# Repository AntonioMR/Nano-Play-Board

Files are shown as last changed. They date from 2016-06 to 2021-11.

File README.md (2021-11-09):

# Nano-Play-Board
Esta placa pretende ser una herramienta de iniciación a la experimentación y aprendizaje de recursos de programación y electrónica con la placa [Arduino Nano 3.x][3] o compatibles.
Dispone de varios sensores, actuadores y puertos para la conexión con otras placas de forma que sea posible explotar parte de las funcionalidades de la plataforma Arduino.

[José Juan Sánchez][1] ha desarrollado una librería para usar la placa que que se encuentra disponile en su [cuenta de github][2]. Esta librería permite un uso fácil de los recursos disponibles en la placa mediante el uso de las clases definidas para los distionts elementos y los metodos para la interactuación con los mismos. 

## Sensores
- Una fotoresistencia conectada al pin de entrada analógica A6.
- Un potenciómetro conectado al pin de entrada analógica A7.
- Cuatro pulsadores conectados a los pines PB0-3 del expansor de GPIO.
- Un acelerómetro de tres ejes conectado a los pines A4 y A5 por medio del bus I2C.
- Un encoder incremental de 16 pasos/revolución conectado a los pines D2 y D5.

## Actuadores
- Un buzzer conectado al canal 7 del driver para LED's.
- Un led RGB conectado a los canales 4, 5 y 6 (rojo, azul y verde respectivamente).
- Una matriz de led's conectada a los pines PA0-7 y PB4-7 del expansor de GPIO, para indicar la columna a encender como el patrón a visualizar en la columna. 

## Puertos
- Un zócalo hembra para conectar un detector de objetos por ultrasonidos conectado a los pines D7 y D8.
- Dos zócalos para conectar foto-receptores de infrarrojos tipo CNY-70 conectados a los pines D6 y D9.
- Un zócalo hembra para conectar un sensor de temperatura y humedad tipo DTH11/DTH22 conectado al pin D12.
- Cuatro zócalos macho para conectar servomotores controlados mediante los canales 0-4 del driver para LED's conectado por I2C.
- Un zócalo hembra para conectar un modulo Bluetooth HC-05/HC-6 mediante los pines D10 y D11.
- Un zócalo hembra para conectar un modulo Wifi ESP8266 mediante los pines D10 y D11.
- Cuatro pads para la conexion de sensores capacitivos a los pines A0, A1, A2 y A3.

## Estructura del repositorio
- Raiz: Fuentes del proyecto de la placa de circuito impreso para el software de diseño de PCB [KiCad][4].
- Gerber : Ficheros de fabricacion en formato Gerber de la placa de circuito impreso.
- Imagenes : Renders de la placa de circuito impreso.
- Pdf : Ficheros para el montaje en formato pdf. Esquema del circuito, situacion de componentes, etc.
- Modelos3D : Modelos 3D en formato .wrl para la visualizacion en el proyecto del diseño de la PCB.
- Soft/lib : Librerías para el uso de los distintos elementos presentes en la placa.
- Soft/src : Ejemplos de uso de la placa. 

## Imagenes
Cara superior
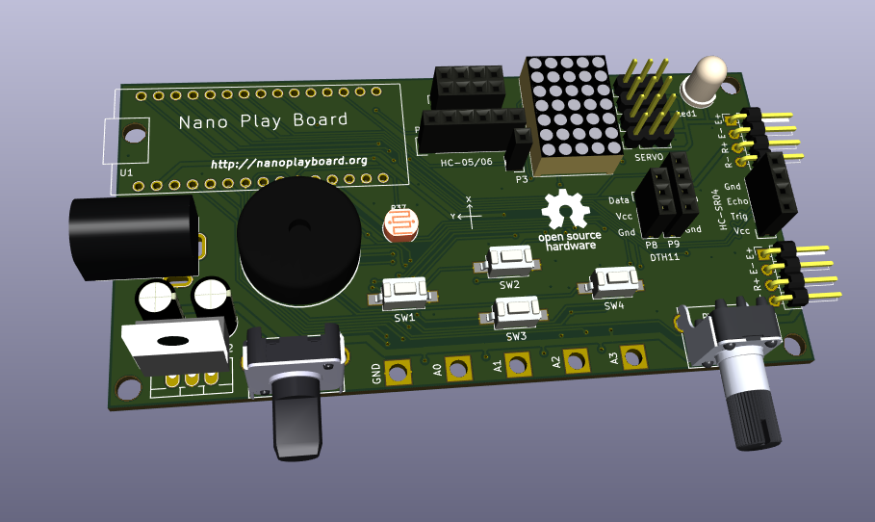
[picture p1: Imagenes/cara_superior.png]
Cara superior


Cara inferior
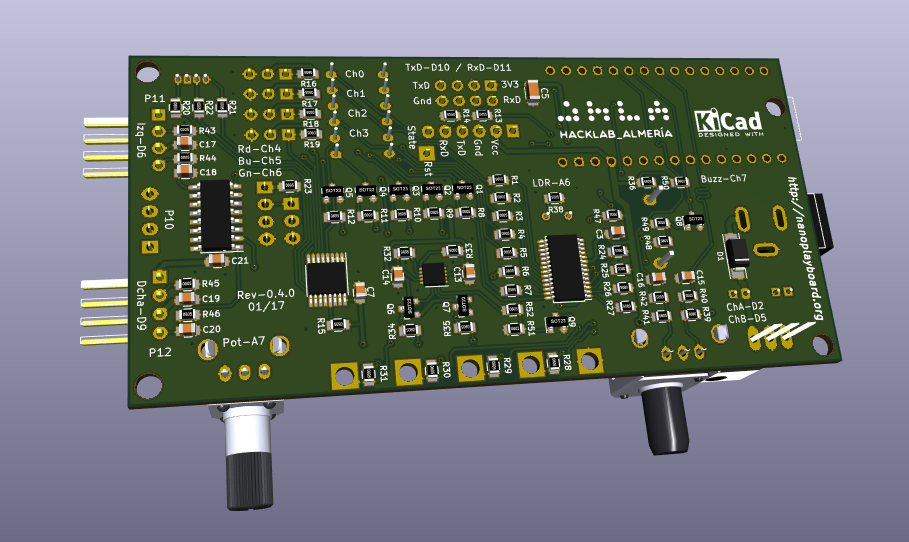
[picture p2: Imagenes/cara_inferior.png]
Cara inferior


## Lista de materiales
Refencias | Valor | Total Uds
----------|-------|-----------
| R1, R2, R20, R21, R22, R3, R4, R5, R6, R7 | [Resistencia 120 Ohm 1/8W](http://www.tme.eu/es/details/crcw0805120rfktabc/resistencias-smd-0805/vishay/) | 10
| R8, R9, R10, R11, R12, R13, R38, R40, R42, R49, R52,  | [Resistencia 1 KOhm 1/8W](http://www.tme.eu/es/details/crcw08051k00fkea/resistencias-smd-0805/vishay/) | 11
| R14 | [Resistencia 2 KOhm 1/8W](http://www.tme.eu/es/details/crcw08052k00fktabc/resistencias-smd-0805/vishay/) | 1
| R23, R32, R33, R34, R35  | [Resistencia 4.7 KOhm 1/8W](http://www.tme.eu/es/details/crcw08054k70fkea/resistencias-smd-0805/vishay/) | 5
| R15, R16, R17, R18, R19, R24, R25, R26, R27, R36, R39, R41, R47, R50 | [Resistencia 10 KOhm 1/8W](http://www.tme.eu/es/details/crcw080510k0fkea/resistencias-smd-0805/vishay/) | 14
| R43, R45  | [Resistencia 220 Ohm 1/8W](http://www.tme.eu/es/details/rc0805fr-07220r/resistencias-smd-0805/yageo/rc0805fr-07220rl/) | 2
| R44, R46, R48, R51  | [Resistencia 47 KOhm 1/8W](http://www.tme.eu/es/details/rc0805fr-0747k/resistencias-smd-0805/yageo/rc0805fr-0747kl/) | 4
| R28, R29, R30, R31 | [Resistencia 10 MOhm 1/8W](http://www.tme.eu/es/details/crcw080510k0fkea/resistencias-smd-0805/vishay/) | 4
| R37 | [Resistencia LDR](http://www.tme.eu/es/details/gm7516/fotoresistencias/wodeyijia/) | 1
| RV1 | [Potenciometro 10K](https://es.rs-online.com/web/p/potenciometros/7293622/)| 1
| C1, C2 | [Condensador electrolitico 0,33 uF 50V](http://www.tme.eu/es/details/uvz1h330mdd/condensadores-electroliticos-tht-105c/nichicon/) | 2
| C18, C20 | [Condensador cerámico 10 nF 25V](http://www.tme.eu/es/details/cl21b103kcannnc/condensadores-mlcc-smd-0805/samsung/) | 2
| C3, C7, C13, C14, C15, C16, C17, C19, C21 | [Condensador cerámico 100 nF 50V](http://www.tme.eu/es/details/cl21b104kbcnnnc/condensadores-mlcc-smd-0805/samsung/) | 7
| C5 | [Condensador ceramico 47 uF 16V](http://www.tme.eu/es/details/cl31a476mqhnnne/condensadores-mlcc-smd-1206/samsung/) | 1
| D1 | [Diodo 15MQ040N](http://www.tme.eu/es/details/15mq040n/diodos-schottky-smd/vishay/15mq040ntrpbf/) | 1
| CON1 | [Conector Barrel Jack 5.5/2.1](http://www.tme.eu/es/details/fc68148/conectores-dc/cliff/) | 1
| P1 | [Tira de pines hembra recto 2x4]() | 1 
| P2 | [Tira de pines hembra recto 1x6]() | 1 
| P4, P5, P6, P7 | [Tira de pines macho recto 1x3]() | 4
| P8 | [Tira de pines hembra recto 1x3]() | 1 
| P10, P9 | [Tira de pines hembra recto 1x4]() | 2 
| P11, P12 | [Tira de pines macho acodado 1x4]() | 2
| P5 | [Tira de pines hembra recto](http://www.tme.eu/es/details/zl262-40sg/regletas-y-enchufes-de-taco/ninigi/) | 3 pines
| P6 | [Tira de pines hembra recto](http://www.tme.eu/es/details/zl262-40sg/regletas-y-enchufes-de-taco/ninigi/) | 4 pines
| U1 | [Arduino Nano](https://www.arduino.cc/en/Main/ArduinoBoardNano) | 1
| U2 | [Regulador de tension 5VDC](http://www.tme.eu/es/details/lm7805ct/estabilizadores-de-tension-no-regulados/fairchild-semiconductor/) | 1
| U3 | [Expansor GPIO, MCP23017](http://www.tme.eu/es/details/mcp23017-e_so/multiplexores-y-conmutadores-analogicos/microchip-technology/) | 1
| U5 | [Matriz de Led's 7x5 Anodo](http://www.tme.eu/es/details/lmd07057bue-101a/pantallas-led-matrices/wenrun/) | 1
| U6 | [Driver para LED 8 canales, PCA9551](http://es.rs-online.com/web/p/drivers-de-display-led/0510730/) | 1
| U8 | [Acelerometro 3 ejes](https://es.rs-online.com/web/p/circuitos-integrados-de-acelerometro/8016873/?sra=pstk) | 1
| U9 | [Inversor CMOS Schmitt Trigger CD40106BM](http://www.tme.eu/es/details/cd40106bm/barreras-inversores/texas-instruments/) | 1
| Q1, Q2, Q3, Q4, Q5, Q8, Q9 | [Transistor NPN SMBT3904](http://www.tme.eu/es/details/smbt3904e6327/transistores-npn-smd/infineon-technologies/)| 7
| Q6, Q7 | [Transistor Mosfet canal N BSS138P](http://www.tme.eu/es/details/bss138p.215/transistores-con-canal-n-smd/nxp/)| 2
| LED1 | [Led RGB 5mm](http://www.tme.eu/es/details/ostama5b31a/diodos-led-tht-5mm/optosupply/)| 1
| SP1 | [Transductor de sonido piezoeléctrico](http://www.tme.eu/es/details/ld-bzpn-1705/transductores-piezoelect-sin-generador/loudity/)| 1
| SW1, SW2, SW3, SW4 | [Pulsador normalmente abierto](http://www.tme.eu/es/details/dtsm31nb/micro-conmutadores-tact-pcb/canal-electronic/dtsm-31n-b/)| 4
| B1 | [Codificador giratorio 2 canales](http://es.rs-online.com/web/p/codificadores-giratorios-mecanicos/6234215/)| 1

## Pines
Referencia | Pin 
----------|-------
| USB Tx | D0 |
| USB Rx | D1 |
| Encoder canal A | D2 |
| Interrupción Acelerómetro / Expansor GPIO | D3 |
| Reset perifericos | D4 |
| Encoder canal B | D5 |
| Infrarrojos Izquierdo | D6 |
| Ultrasonidos Echo | D7 |
| Ultrasonidos Trigg | D8 |
| Infrarrojos Derecho | D9 |
| Inalámbrico Tx | D10 |
| Inalámbrico Rx |  D11 |
| Sensor DTH Dato | D12 |
| Libre (LED Arduino) | D13 |
| Pad para sensor capacitivo 0 | A0 |
| Pad para sensor capacitivo 1 | A1 |
| Pad para sensor capacitivo 2 | A2 |
| Pad para sensor capacitivo 3 | A3 |
| I2C - SDA | A4 |
| I2C - SCL | A5 |
| LDR | A6 |
| Potenciometro | A7 |

## Licencia
Este diseño es Software Libre; usted puede redistribuirlo y/o modificarlo bajo los términos de la "GNU General Public License" como lo publica la "FSF Free Software Foundation", o (a su elección) de cualquier versión posterior.

Este diseño es distribuido con la esperanza de que le sea útil, pero SIN NINGUNA GARANTIA; incluso sin la garantía implícita por la VENTA o EJERCICIO DE ALGUN PROPOSITO en particular. Vea la "GNU General Public License" para más detalles.

## Creditos
Los modelos 3D de los siguientes componentes están creados a partir de los modelos originales indicados a continuación:

Componente | Autor | Modelo 
-----------|-------|--------
| Arduino Nano V3 | [Carlos AG][5] | [Modelo][6] 
| Bluetooth HC-06 | [Felix Georgievich ILgach][7] | [Modelo][8] 
| Detector HC-SR04 | [Renato Alonso Hurtado Medina][9] | [Modelo][10] 

[1]: http://josejuansanchez.org
[2]: https://github.com/josejuansanchez/NanoPlayBoard/
[3]: https://www.arduino.cc/en/Main/ArduinoBoardNano
[4]: http://kicad.org/
[5]: http://www.3dcontentcentral.com/Contributors.aspx?id=669699
[6]: http://www.3dcontentcentral.com/parts/download-part.aspx?id=387975&catalogid=171
[7]: http://www.3dcontentcentral.com/Contributors.aspx?id=1658685
[8]: http://www.3dcontentcentral.com/download-model.aspx?catalogid=171&id=542660
[9]: http://www.3dcontentcentral.com/Contributors.aspx?id=1704559
[10]: http://www.3dcontentcentral.com/download-model.aspx?catalogid=171&id=655885

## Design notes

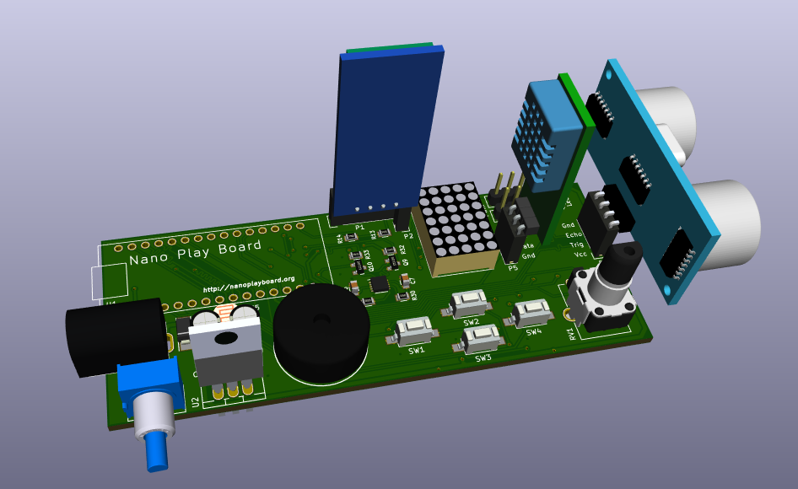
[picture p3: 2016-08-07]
Imagenes/Sensores_cara_superior.png

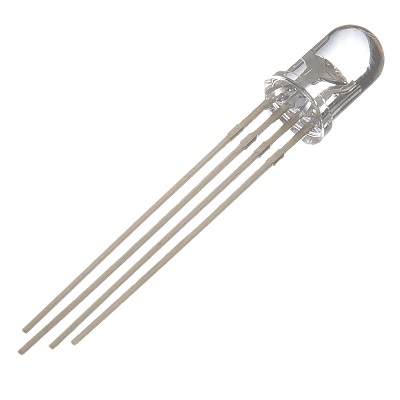
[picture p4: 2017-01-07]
Imagenes/rgb-led.jpg

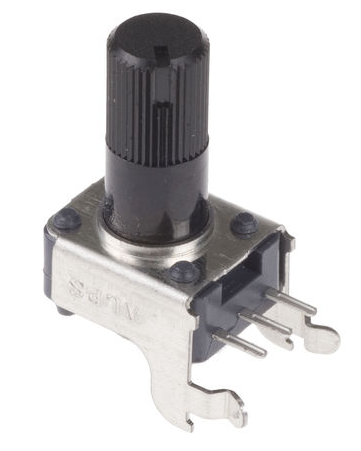
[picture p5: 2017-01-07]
Imagenes/Potenciometro.png

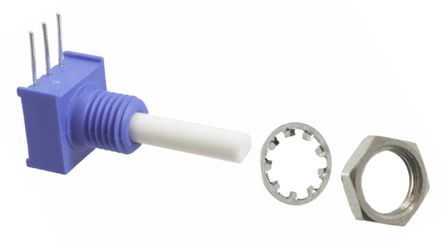
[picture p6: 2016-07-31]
Imagenes/Encoder_3315C.jpg

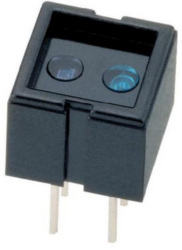
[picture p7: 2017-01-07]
Imagenes/CNY70.jpg

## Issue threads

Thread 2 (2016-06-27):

Pin A7 usado como salida

AntonioMR, 2016-06-27:
Los pines A6 y A7 son pines analógicos puros y no pueden usarse como E/S digitales.
La placa utiliza el pin A7 para la carga de las salidas en el registro de desplazamiento y es necesario puentearlo con el pin D6, que está libre para poder usarse el registro.

AntonioMR, 2016-07-18:
Corregido en la revisión "a" de la placa. Para las versiones anteriores es necesario realizar un puente externo

Closed 2016-07-18.

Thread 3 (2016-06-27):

Propuesta - Utilizar 2 salidas PWM para controlar 2 servos

josejuansanchez, 2016-06-27:
Para una nueva versión estaría genial usar 2 salidas PWM para controlar dos servos.
Se podrían poner dos tiras de 3 pines macho, para controlar la señal PWM, el voltaje y la tierra.
Aquí pongo una imagen de una placa que usa estas tiras de pines.

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

AntonioMR, 2016-08-07:
Se han añadido dos conectores macho de tres pines en la versión 0.2 de la placa controlados por los pines D5 y D6 junto con VCC y GND

Closed 2016-08-07.

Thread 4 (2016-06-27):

Propuesta - Añadir un pulsador

josejuansanchez, 2016-06-27:
También se podría incluir un pulsador para permitir realizar experimentos que incluyan este nuevo elemento. De este modo incrementamos el número de prácticas que se pueden realizar con la placa.

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

AntonioMR, 2016-07-21:
Seria interesante añadir incluso varios aunque hubiera que añadir un codificador de 8 a 3 lineas y leer mediante 3 bits hasta 8 pulsadores.
En cualquier caso, uno es imprescindible.

AntonioMR, 2016-08-07:
Añadidos 4 pulsadores conectados mediante un codificador de prioridad en la versión 0.2

Closed 2016-08-07.

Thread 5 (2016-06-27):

Propuesta - Añadir una tira de 4 pines hembra para un sensor de ultrasonidos

josejuansanchez, 2016-06-27:
Estaría bien incluir una tira de 4 pines hembra para poder conectar un sensor de ultrasonidos directamente en la placa.

En la imagen se muestra el tipo de sensor de ultrasonido con los que la placa podría ser compatible.

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

josejuansanchez, 2016-07-21:
No tengas en cuenta esta propuesta, creo que es mejor utilizar pines macho como los que usan en esta placa:

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

AntonioMR, 2016-07-21:
No me parece mala idea poner un zócalo hembra para insertar directamente el modulo, seria mas practico que tener que andar poniendo cables.
La sigo teniendo en mente.

AntonioMR, 2016-08-07:
Añadido en la versión 0.2

Closed 2016-08-07.

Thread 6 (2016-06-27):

Propuesta - Añadir una tira de 4 pines hembra para conectar un módulo bluetooth

josejuansanchez, 2016-06-27:
Se podrían incluir 4 pines hembra para conectar directamente un módulo de bluetooth sobre la placa.

La placa podría ser compatible con los módulos bluetooth HC-05 y HC-06.

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

josejuansanchez, 2016-07-21:
Creo que esto no sería necesario, he estado haciendo pruebas con un módulo bluetooth HC-05 conectado a los pines  **D7 (Rx)** y **D8 (Tx)** y creo que así está perfecto.

Lo que sí podría ser interesante es añadir dos pines macho adicionales de **+5v** y **GND** junto a los pines **Rx** y **Tx**.

AntonioMR, 2016-07-21:
La idea original de esos pines era conectarse con otras placas iguales para comunicarse. Sin duda con los pines de alimentación mucho mas practico para conectar directamente el modulo blueooth.

Closed 2016-07-21.

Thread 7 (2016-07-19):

Propuesta - Añadir un pequeño sensor de temperatura similar al de `LightBlue Bean`

josejuansanchez, 2016-07-19:
Se podría estudiar la posibilidad de incluir un pequeño sensor de temperatura similar al que lleva la placa `LightBlue Bean`.

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

AntonioMR, 2016-08-07:
Se añade un zócalo para un sensor DTH11/DTH22 en la versión 0.2 de la placa

Closed 2016-08-07.

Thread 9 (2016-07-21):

Propuesta - Pinout para la próxima versión

josejuansanchez, 2016-07-21:
Aquí dejo una posible propuesta de cómo podría ser el *pinout* de la próxima versión.
He resaltado en negrita los cambios que he propuesto respecto a la versión actual.

## Pines
Referencia | Pin
----------|-------
| **Rx**. Para el módulo Bluetooth | **D0** |
| **Tx**. Para el módulo Bluetooth | **D1** |
| Activación de la primera columna de la matriz | D2 |
| Altavoz piezoelectrónico | D3 (PWM) |
| Activación de la segunda columna de la matriz | D4 |
| **Servo**. (Pines macho) | **D5 (PWM)** |
| **Servo**. (Pines macho) | **D6 (PWM)** |
| **Sensor IR**. (Pines macho) | **D7** |
| **Sensor IR**. (Pines macho) | **D8** |
| Pin Rojo RGB | D9 (PWM) |
| Pin Verde RGB | D10 (PWM) |
| Pin Azul RGB | D11 (PWM) |
| Dato de entrada al registro de desplazamiento | D12 |
| Reloj de carga serie del registro de desplazamiento | D13 |
| Fotoresistencia | A0 |
| Potenciometro | A1 |
| Activación de la cuarta columna de la matriz | A2 |
| Activación de la quinta columna de la matriz | A3 |
| **Activación de la tercera columna de la matriz** | **A4** |
| **Reloj de carga de las salidas del registro de desplazamiento** | **A5** |
| **Pulsador** | **A6** |
| **¿Pulsador o Sensor de temperatura?** | **A7** |

AntonioMR, 2016-07-21:
Muchas gracias por todas las sugerencias, sin duda mejoraran mucho la placa y la haran mas util a la hora de enseñar cosas con ella. Te comento lo que tenia en mente para la evolucion de la placa.
Tenia en mente añadir un segundo registro en serie con el primero para controlar la activación de las columnas de la matriz, de modo que el primer byte enviado es el dato de la columna y el segundo la columna o columnas que se activara. Esto libera 5 pines digitales. de los que tres quería utilizar para el codificador de los pulsadores
Los pines A4 y A5 como son los que implementan el bus I2C tenia pensado aprovecharlos para conectar algún tipo de acelerómetro, sensor Tª o cualquier sensor I2C que se integrara dentro de la placa.
Como el pin D2 soporta una interrupción externa ando dándole vueltas a como utilizarlo para que se pueda aprovechar esta funcionalidad, había pensado en un contador de pulsos o algo así.
Para añadir todo esto en el mismo espacio, todas las resistencias y probablemente los transistores pasen a versiones SMD de un tamaño razonable como para que se puedan soldar con relativa facilidad.

josejuansanchez, 2016-07-21:
La evolución de la placa que propones me parece brillante!

AntonioMR, 2016-08-07:
Finalmente la versión 0.2 de la placa ha quedado con la siguiente distribución de pines

## Pines
Referencia | Pin
----------|-------
| Tx. Para el módulo Bluetooth | D0 |
| Rx. Para el módulo Bluetooth | D1 |
| Encoder canal A | D2 |
| Altavoz piezoelectrico | D3 (PWM) |
| Reloj de carga de las salidas de los registros | D4 |
| Servo 1. (Pines macho) | D5 (PWM) |
| Servo 2. (Pines macho) | D6 (PWM) |
| Ultrasonidos Echo. (Pines macho) | D7 |
| Ultrasonidos Trig. (Pines macho) | D8 |
| Pin Rojo RGB | D9 (PWM) |
| Pin Verde RGB | D10 (PWM) |
| Pin Azul RGB | D11 (PWM) |
| Dato de entrada al registro de desplazamiento | D12 |
| Reloj de carga serie del registro de desplazamiento | D13 |
| Pulsadores bit 0 | A0 |
| Pulsadores bit 1 | A1 |
| Encoder canal B | A2 |
| Dato sensor Tª/HR  | A3 |
| Linea SDA del bus I2C para conexión con acelerómetro | A4 |
| Linea SCL del bus I2C para conexión con acelerómetro| A5 |
| Fotorresistencia | A6 |
| Potenciómetro | A7 |

josejuansanchez, 2016-09-16:
Creo que no ha sido buena idea usar los pines `D0` y `D1` para el módulo Bluetooth. Tenías razón, nos limita las posibilidades de uso de la placa y no es nada cómodo estar quitando el módulo Bluetooth cada vez que se sube un *sketch*.

Siento haberte dado la lata para que lo cambiaras :(
Si se puede cambiar en la próxima versión estaría genial.

AntonioMR, 2016-09-16:
En la próxima versión, si todos los pines PWM pasan a controlarse mediante un driver para leds controlado por I2C, se liberarían 6 pines:
2 para puerto serie destinado a comunicaciones inalámbricas (bluetooth, wifi, xbee ...)
1 para la interrupción del acelerómetro
2 para el decodificador de pulsadores y poder controlar hasta 8 pulsadores (un piano? seria genial poder llegar hasta doce y poder tener una octava con los semitonos y todo). Sobre todo pensando en la placa como controladora midi lanzando samplers.
quedaría uno libre que ya se nos ira ocurriendo, quizás para aumentar el numero de pulsadores.

AntonioMR, 2016-09-25:
Una propuesta para la proxima revision:

## Pines
Referencia | Pin
----------|-------
| Tx. Para la comunicación USB | D0 |
| Rx. Para la comunicación USB | D1 |
| Encoder canal A | D2 |
| Canal de interrupcion del acelerometro | D3 (PWM) |
| Reloj de carga de las salidas de los registros | D4 |
| Tx. Para el módulo Bluetooth | D5 (PWM) |
| Rx. Para el módulo Bluetooth | D6 (PWM) |
| Ultrasonidos Echo. (Pines macho) | D7 |
| Ultrasonidos Trig. (Pines macho) | D8 |
| Pulsadores bit 2 | D9 (PWM) |
| Pulsadores bit 3 | D10 (PWM) |
| Pulsadores bit pulsación | D11 (PWM) |
| Dato de entrada al registro de desplazamiento | D12 |
| Reloj de carga serie del registro de desplazamiento | D13 |
| Pulsadores bit 0 | A0 |
| Pulsadores bit 1 | A1 |
| Encoder canal B | A2 |
| Dato sensor Tª/HR  | A3 |
| Linea SDA del bus I2C para conexión con acelerómetro y driver de LED's | A4 |
| Linea SCL del bus I2C para conexión con acelerómetro y driver de LED's | A5 |
| Fotorresistencia | A6 |
| Potenciómetro | A7 |

Se utilizaría un codificador con prioridad de 16 a 4 para leer el estado de 12 pulsadores distribuidos como teclado de piano formando una octava.

Los 2 servos, el buzzer y el led RGB pasarían a estar controlados por el driver para LED PCA9685 capaz de generar hasta 16 señales PWM independientes. Se utilizarían 5 y el resto se pueden utilizar para encender LED's junto a los pulsadores

MiguelAngelLV, 2016-11-21:
Para una futura revisión, se podría cambiar el LED RGB por uno basado en el ws2812, estos requieren un solo pin PWM. Quizás sea más fácil que usar el bus del i2c o dejarlo libre para otro dispositivo.

También, para ahorrar 1 GPIO en los botoenes, podríamos usar este esquema:

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

Con 3 PINs podríamos tener hasta 6 botones. Envías corriente por A0, si recibes en A1 estás pulsando el B0 y si te llega por el A2 estás pulsando el B1.

Ahora cambias el modo y envías por A1, si recibes por A0 estás pulsando B2 y si recibes por A2 estás pulsando B3.

Igualmente podríamos hacerlo enviando por A2 y comprobando A0 y A1 para obtener 2 botones más.

Tendríamos que tener unos delays de microsegundos (pongamos 20 microsegundos por par de botones), pero no creo que sea apreciable.

AntonioMR, 2016-11-21:
Interesantes ambas propuestas, tomo nota.

MiguelAngelLV, 2016-11-21:
Chachi. Bueno, se me había olvidado comentar que los LEDs ws2812 puedes ponerlos en serie y conectar todos los que quieras. Así con un solo PIN puedes poner todos los LEDs que te de la gana. Yo creo que con 4 podrían hacerse cosas muy chulas.

AntonioMR, 2017-01-04:
Propuesta para la V3 de la placa

| Referencia | Pin |
| --- | --- |
| Tx. Para la comunicación USB | D0 |
| Rx. Para la comunicación USB | D1 |
| Encoder canal A | D2 |
| Canal de interrupcion del acelerometro | D3 (PWM) |
| Reloj de carga de las salidas de los registros | D4 |
| Encoder canal B | D5 (PWM) |
| Infrarrojos Izquierdo | D6 (PWM) |
| Ultrasonidos Echo. (Pines macho) | D7 |
| Ultrasonidos Trig. (Pines macho) | D8 |
| Infrarrojos Derecho | D9 (PWM) |
| Tx. Para el módulo Bluetooth  | D10 (PWM) |
| Rx. Para el módulo Bluetooth  | D11 (PWM) |
| Dato de entrada al registro de desplazamiento | D12 |
| Reloj de carga serie del registro de desplazamiento | D13 |
| Pulsadores bit 0 | A0 |
| Pulsadores bit 1 | A1 |
| Pulsadores - Detección pulsación | A2 |
| Dato sensor Tª/HR | A3 |
| Linea SDA del bus I2C para conexión con acelerómetro y driver de LED's | A4 |
| Linea SCL del bus I2C para conexión con acelerómetro y driver de LED's | A5 |
| Fotorresistencia | A6 |
| Potenciómetro | A7 |

Incluiría un driver para Led controlado por I2C para 8 canales (4 servos, Led RGB)

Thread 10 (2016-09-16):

Errata en la serigrafía de los pines del registro de desplazamiento de la nueva placa Rev-0.2

josejuansanchez, 2016-09-16:
Los pines del registro de desplazamiento aparecen en la placa como:

```
Din    = D13
ClkIn  = D12
ClkOut = D4
```

pero en el esquema aparecen como:

```
Din    = D12
ClkIn  = D13
ClkOut = D4
```

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

AntonioMR, 2016-09-16:
Gracias por avisar.
La serigrafía esta mal, están rutados conforme al esquema!

Closed 2016-09-16.

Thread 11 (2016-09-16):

El pulsador superior esta inutilizado

AntonioMR, 2016-09-16:
De la forma que están conectados los pulsadores al decodificador no es posible utilizar el pulsador superior ya que seria necesario comprobar el estado del pin de salida GS del decodificador.

AntonioMR, 2016-11-21:
Una posible solución para utilizar el pulsador con las placas versiones 0.2.0 y 0.2.1 es tirar un hilo entre el terminal GS del codificador (patilla 14) y el pin 2 en el zócalo para la conexión del sensor DHT11.
De esta forma se utilizará el Pin A3 del Arduino Nano como entrada digital. Está estará a nivel bajo si algun pulsador está activo. La combinacion de los pines A0 y A1 será
A0 | A1 | Pulsador
 0  |   0  | Arriba
 1  |   0  | Izquierda
 0  |   1  | Derecha
 1  |   1  | Abajo

AntonioMR, 2017-01-25:
Corregido a partir de la V0.3

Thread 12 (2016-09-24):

Controlar las señales PWM mediante un driver para LED's

AntonioMR, 2016-09-24:
Añadir un driver para LED'S controlado medante I2C para las señales PWM de los servos, Led RGB y buzzer, y así dejar libres esas salidas del micro para otras funciones.

AntonioMR, 2017-01-25:
Realizado a partir de la V0.3

Closed 2017-01-25.

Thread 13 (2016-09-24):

Conectar la salida de interrupción del acelerómetro

AntonioMR, 2016-09-24:
Conectar la salida de interrupción de acelerómetro al pin D3 del arduino de forma que se pueda hacer uso de la capacidad de generar interrupciones del chip MMA7660FC.
Previamente ha de liberarse este pin que se usa para generar la señal PWM del buzzer

AntonioMR, 2017-01-25:
Conectado a partir de la versión V0.3

Closed 2017-01-25.

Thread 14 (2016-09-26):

Observaciones sobre la NanoPlayBoard Rev-0.2

josejuansanchez, 2016-09-26:
- Me gustaba más el tacto del potenciómetro de la versión anterior de la placa. El de la versión actual resbala un poco y no gira con tanta suavidad como el otro.
- Cuando el sensor de ultrasonidos está montado en la placa resulta un poco complicado manipular el potenciómetro.
- He tenido algunos problemas de conexión con mi sensor DHT 11, no hacía buen contacto, tenía que moverlo o mantenerlo presionado para que hiciese buen contacto. También habría que revisar el orden de los pines hembra de la placa, porque puede ser que no coincida con los pines del sensor. Propongo buscar un sensor de temperatura barato e integrarlo en la placa directamente como el acelerómetro.
- Estaría bien añadir algunos pines macho de propósito general para poder conectar otros sensores/actuadores de otros kits de robótica/electrónica. Por ejemplo serían ideales para conectar dos sensores de infrarrojos y poder hacer un robot siguelíneas. Yo propondría entre 2 y 4 pines más de propósito general siguiendo el mismo estilo de los pines actuales de los servos (Señal, Vcc y Gnd).
- Habría que ver la posibilidad de poner los pines macho de diferentes colores, rojo para Vcc, negro para Gnd y otro color diferente para la Señal. Esto podría ser de ayuda a los más pequeños a la hora de conectar los componentes a la placa.
- ¿Sería posible añadirle algunos pads para usarlos como sensores capacitivos? Adafruit ha sacado hace poco una placa que los tiene, [aquí le puedes echar un vistazo](https://www.adafruit.com/product/3000).
- Para poder añadir un ESP8266 necesitaríamos dos pines de 3.3v. ¿Sería posible añadirlos en la próxima versión?

AntonioMR, 2016-09-26:
Gracias por los comentarios @josejuansanchez

El gran problema de la placa es el espacio. La próxima versión será de 100x50 mm (10 mm mas ancha) ya que tiene el mismo coste y ayudara a distribuir mejor los componentes. Esto ayudará con la usabilidad del potenciómetro cuando el sensor de ultrasonidos este conectado (cosa que ya me temía viendo el modelo en 3D) y del sensor de Tª que también se queda muy justo sobre los conectores de los servos.
Coincido contigo en el sensor de Tª integrado en la placa, y si es I2C liberará un pin para nuevos propósitos.

Lo del potenciómetro tiene fácil solución ya que el otro creo que era incluso mas barato. A mi particularmente me gusta mas el tacto de este, con el punto central claramente identificado en la carrera, pero vamos, ambos utilizan la misma huella por lo que poner uno u otro es cosa simple.

Lo de los pines de propósito general me parece interesante, aunque dado la densidad de señales que tratamos de controlar con la placa probablemente tenga que compartir funcionalidad con alguna otra característica. Intentare ver la forma de tener al menos 2 con dedicación exclusiva.

Lo de los pines de colores es una mera cuestión de coste. Lo tendré en cuenta a la hora de diseñarlo ya que si se posicionan los conectores adecuadamente lo mismo no incrementa mucho el coste y es verdad que es una gran ayuda. Mucho mas intuitivo que las indicaciones en la serigrafía.

Me gusta lo de la posibilidad de tener pads para usar sensores capacitivos y mas aun si estos compartieran pin físico en el arduino con los pulsadores físicos. Me temo que esto implicaría no aumentar el numero de pulsadores y que cada uno utilice un pin físico del Arduino. Le daré un vistazo a la opción de 4 pulsadores con pad en el borde de la placa al que conectar los posibles sensores.

Lo del ESP8266 no tiene mayor problema, solo que lo mas probable es que comparta pines con el modulo bluetooth (dos distintos al D0 y D1 utilizado por el USB)

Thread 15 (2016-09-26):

Comprobar la distribución de pines en el sensor DHT11

AntonioMR, 2016-09-26:
La placa utiliza una distribución de pines VCC, Data, GND. Algunos de estos sensores utilizan VCC, GND, Data.

AntonioMR, 2017-01-25:
La Version V0.4 corrige este problema y además incorpora zócalos para conectar tanto la versión de 3 pines cómo la de 4

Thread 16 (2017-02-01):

Modificacion en Encoder a partir de V0.2.1

AntonioMR, 2017-02-01:
A partir de la versión V0.2.1 se monta un encoder con mas pasos por revolución y es necesario bajar los valores de los condensadores y resistencias del filtro anti-rebotes. Con los valores especificados en el esquema se obtienen resultados erráticos a baja velocidad de giro.
Se ha probado el encoder con valores de 1KOhm para las resistencias y 100nF para los condensadores obteniendo resultados según lo esperado. Las resistencias de pull-up se mantienen a 10KOhm.

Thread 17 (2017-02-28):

Huella de U3 no corresponde

AntonioMR, 2017-02-28:
En la version V0.4.0 se utiliza la huella del paquete TSSOP28 cuando el encapsulado es un SSOP28.
Se corregirá en la siguiente revision

AntonioMR, 2017-03-03:
Corregido en V0.4.1

Closed 2017-03-23.

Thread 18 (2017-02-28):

La huella de U9 no corresponde

AntonioMR, 2017-02-28:
En la version V0.4.0 se ha utilizado una huella para SOIC16 cuando el encapsulado es un SOIC14.
En necesario realizar puentes de forma externa para que pueda funcionar esta PCB.
Pendiente de corregir en la siguientes revision

AntonioMR, 2017-03-03:
corregido en V0.4.1

Closed 2017-03-23.

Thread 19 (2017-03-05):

Driver para led no permite ciclos de trabajo independientes por canal

AntonioMR, 2017-03-05:
El driver para led PCA9551 solo permite dos ciclo de trabajo configurables para todos los canales.
Es necesario utilizar un driver con control independiente para cada canal, como por ejemplo el PCA9684

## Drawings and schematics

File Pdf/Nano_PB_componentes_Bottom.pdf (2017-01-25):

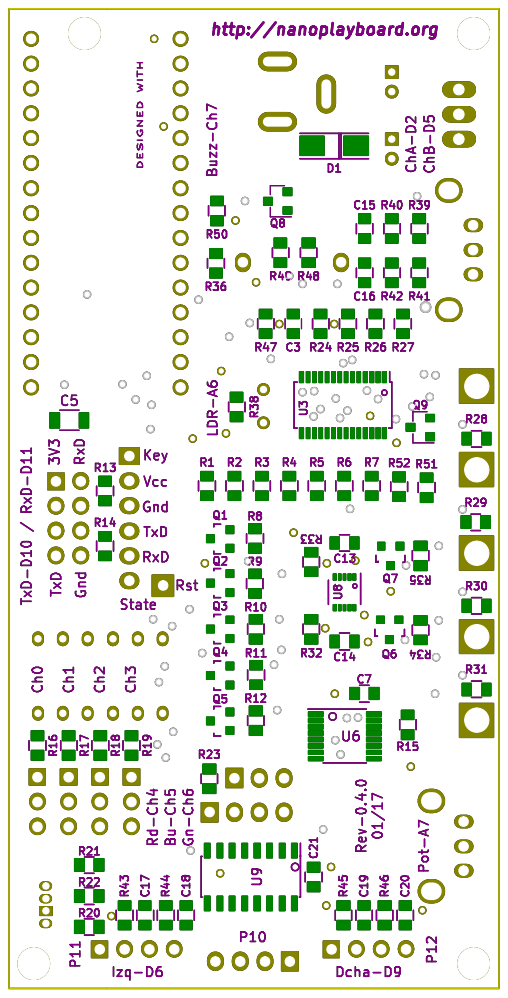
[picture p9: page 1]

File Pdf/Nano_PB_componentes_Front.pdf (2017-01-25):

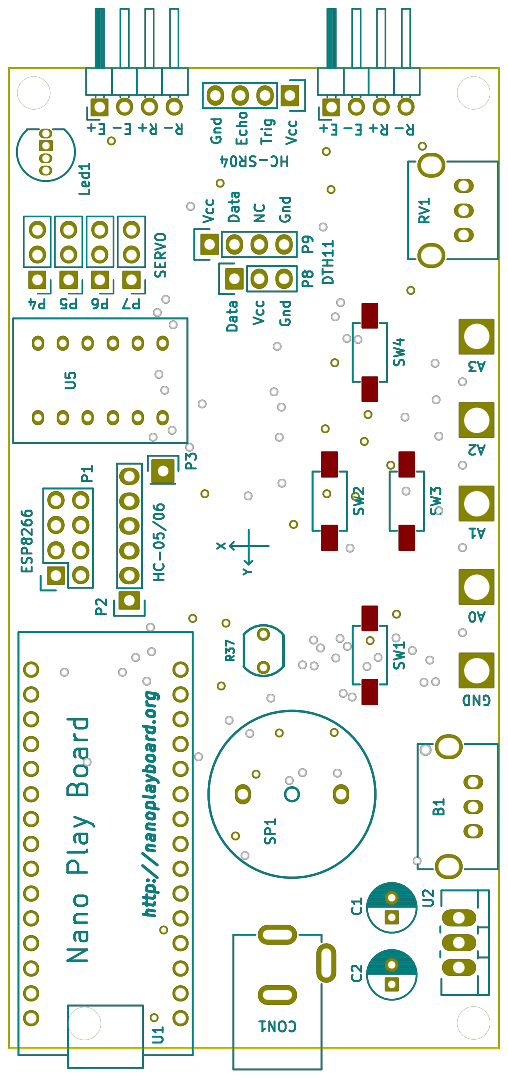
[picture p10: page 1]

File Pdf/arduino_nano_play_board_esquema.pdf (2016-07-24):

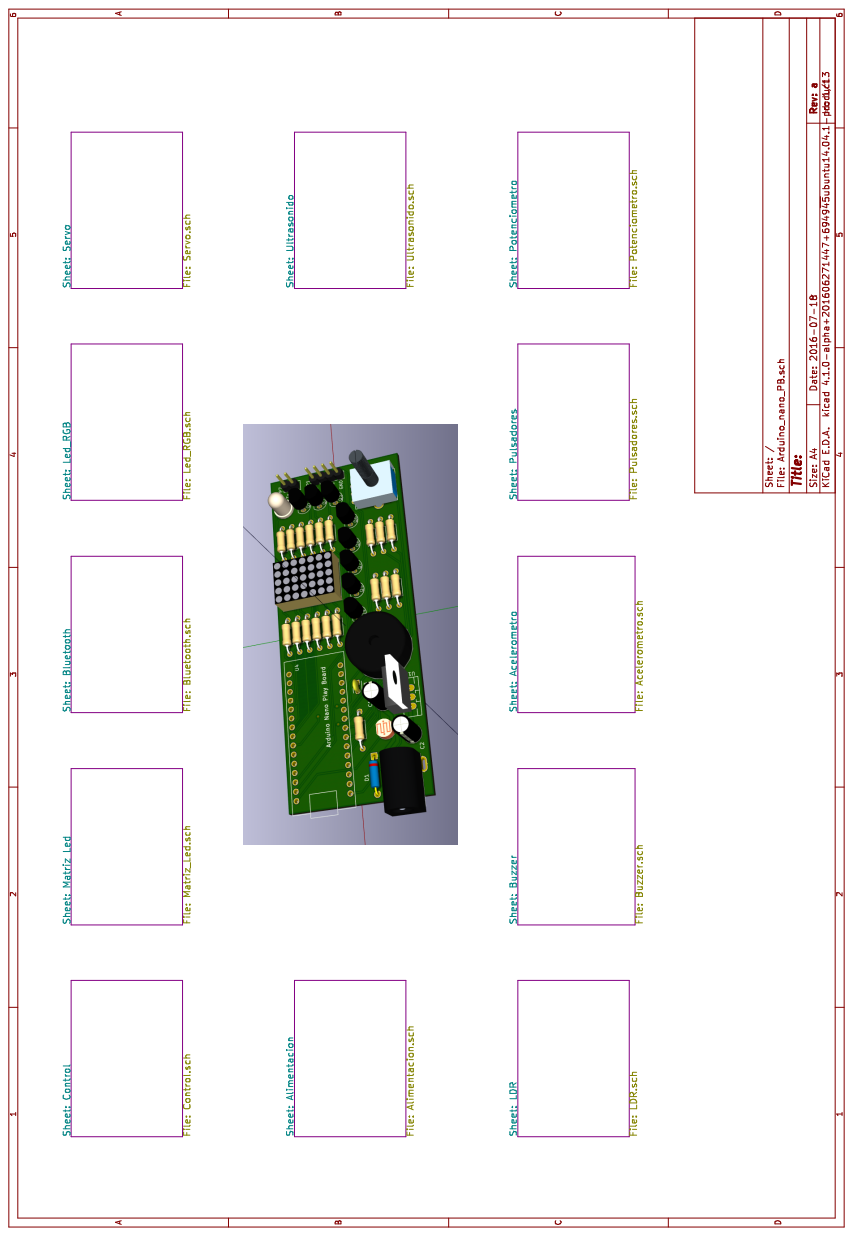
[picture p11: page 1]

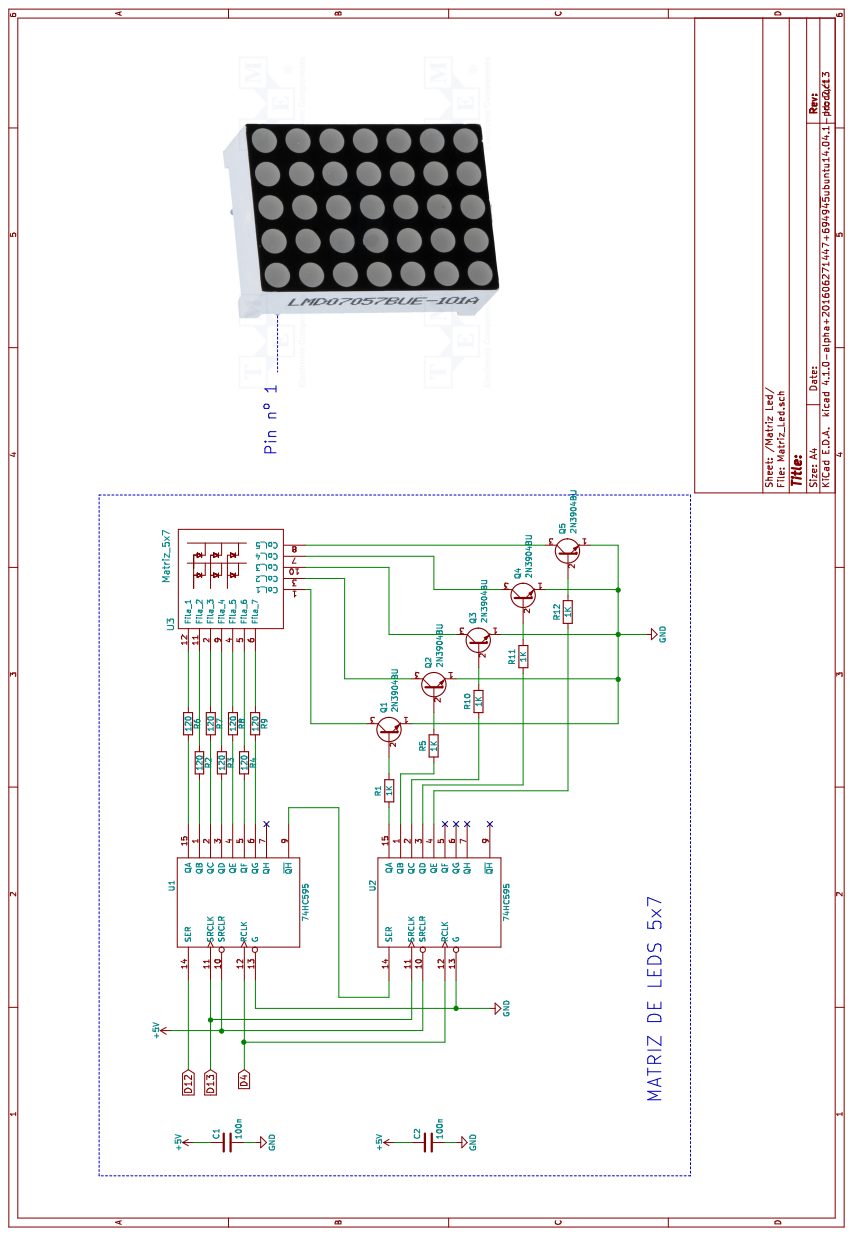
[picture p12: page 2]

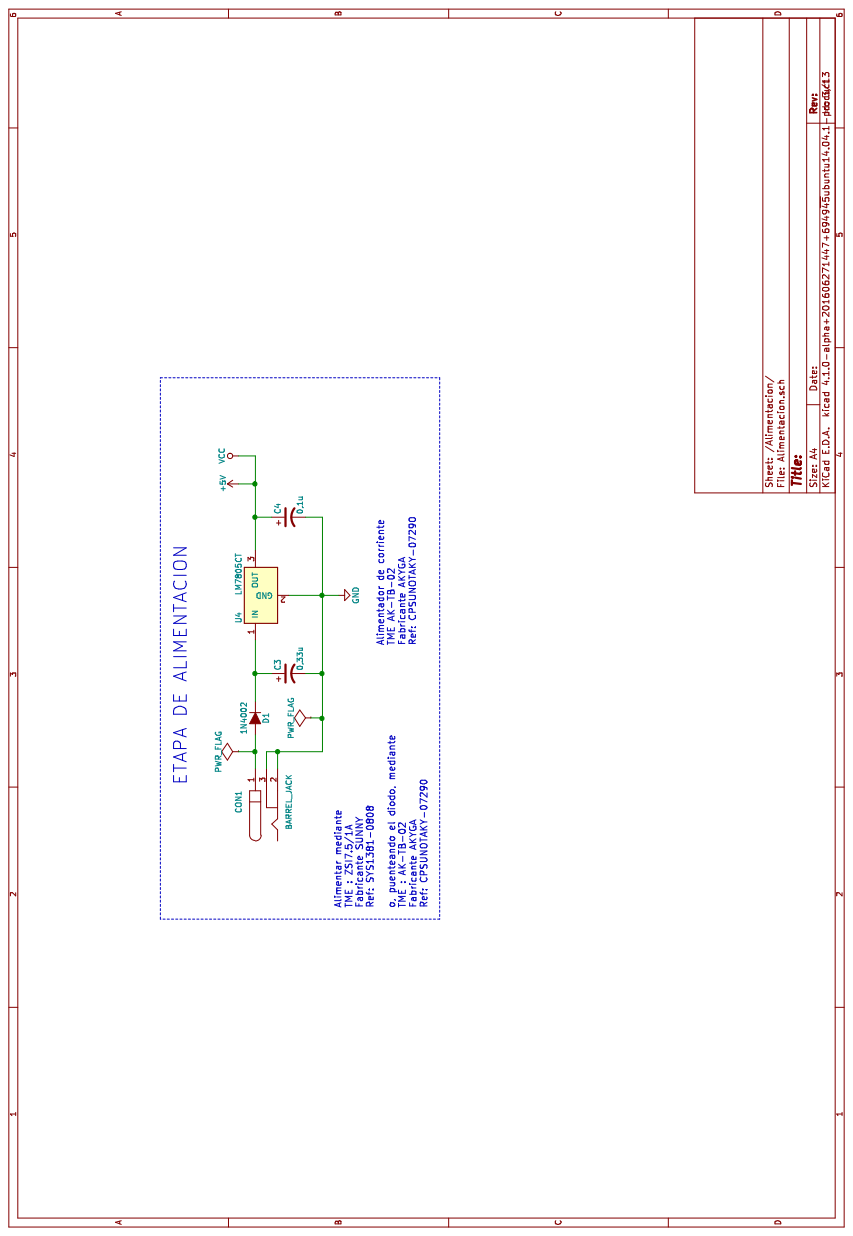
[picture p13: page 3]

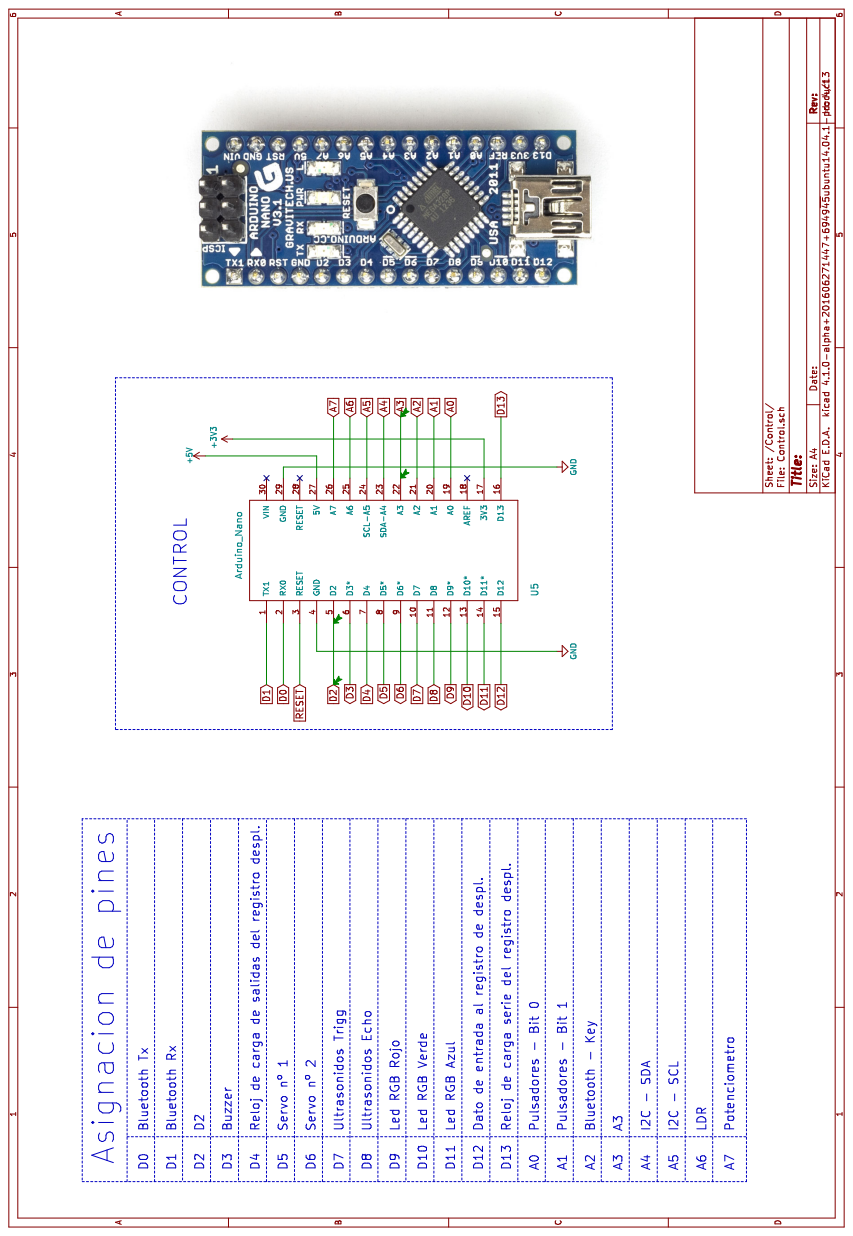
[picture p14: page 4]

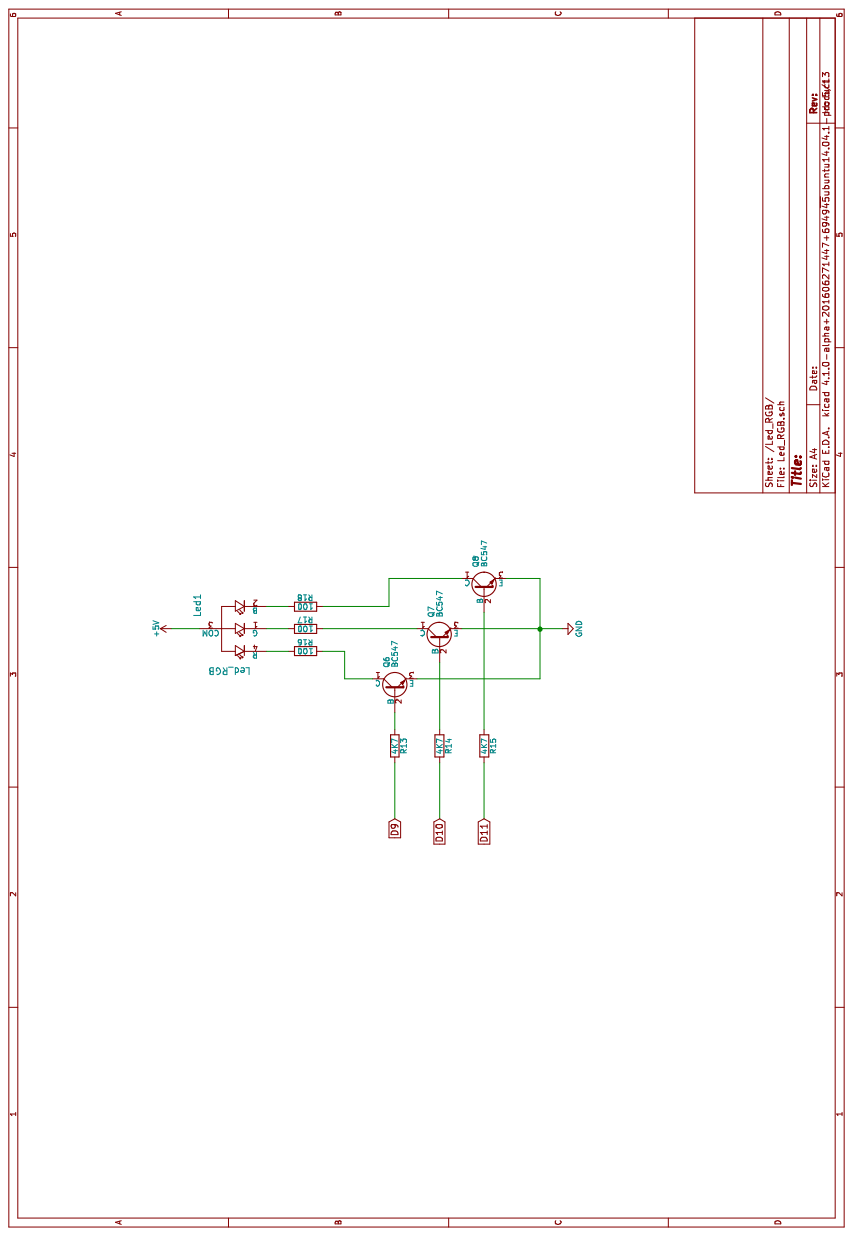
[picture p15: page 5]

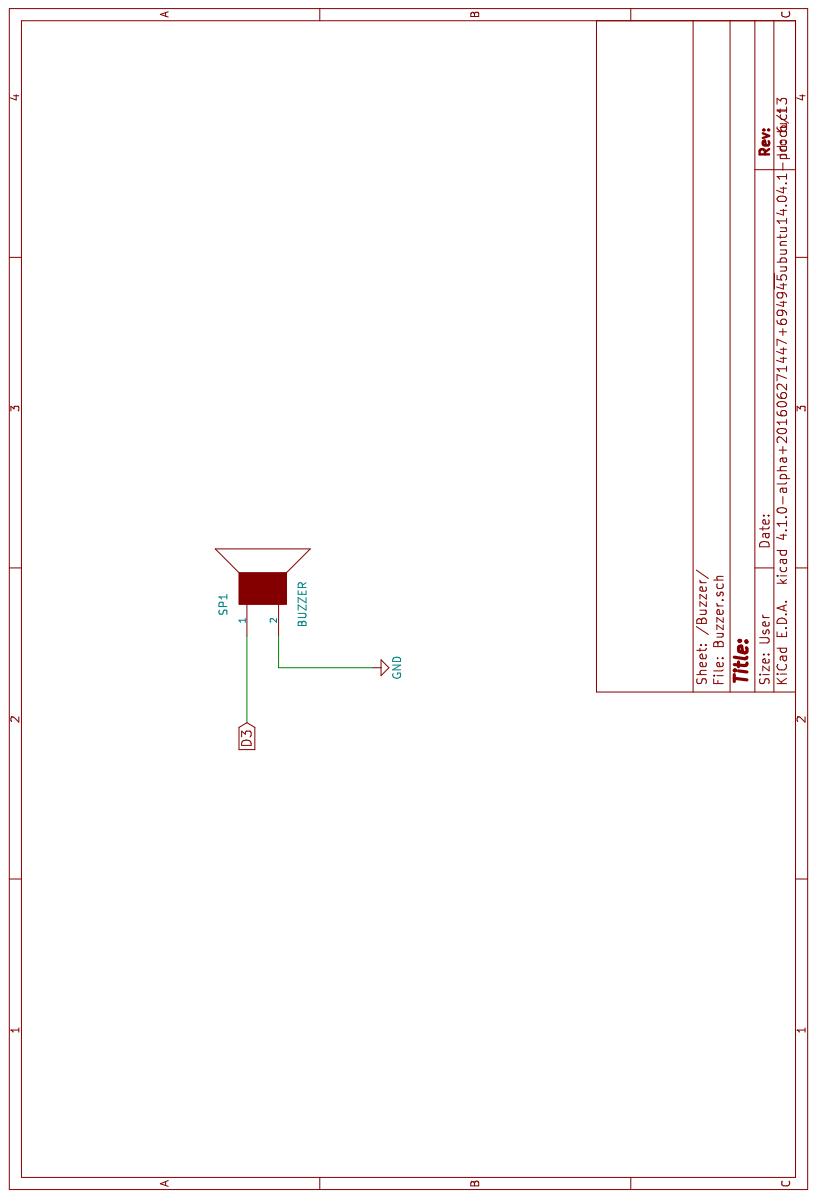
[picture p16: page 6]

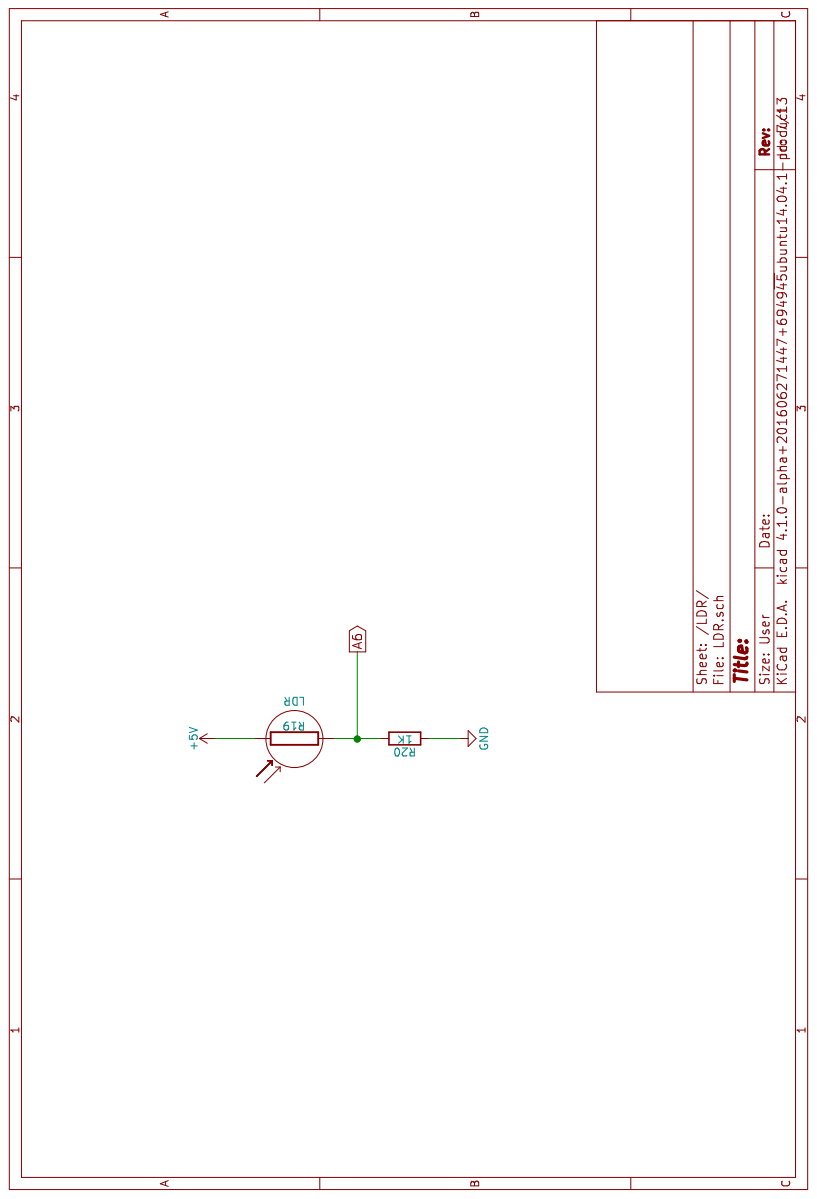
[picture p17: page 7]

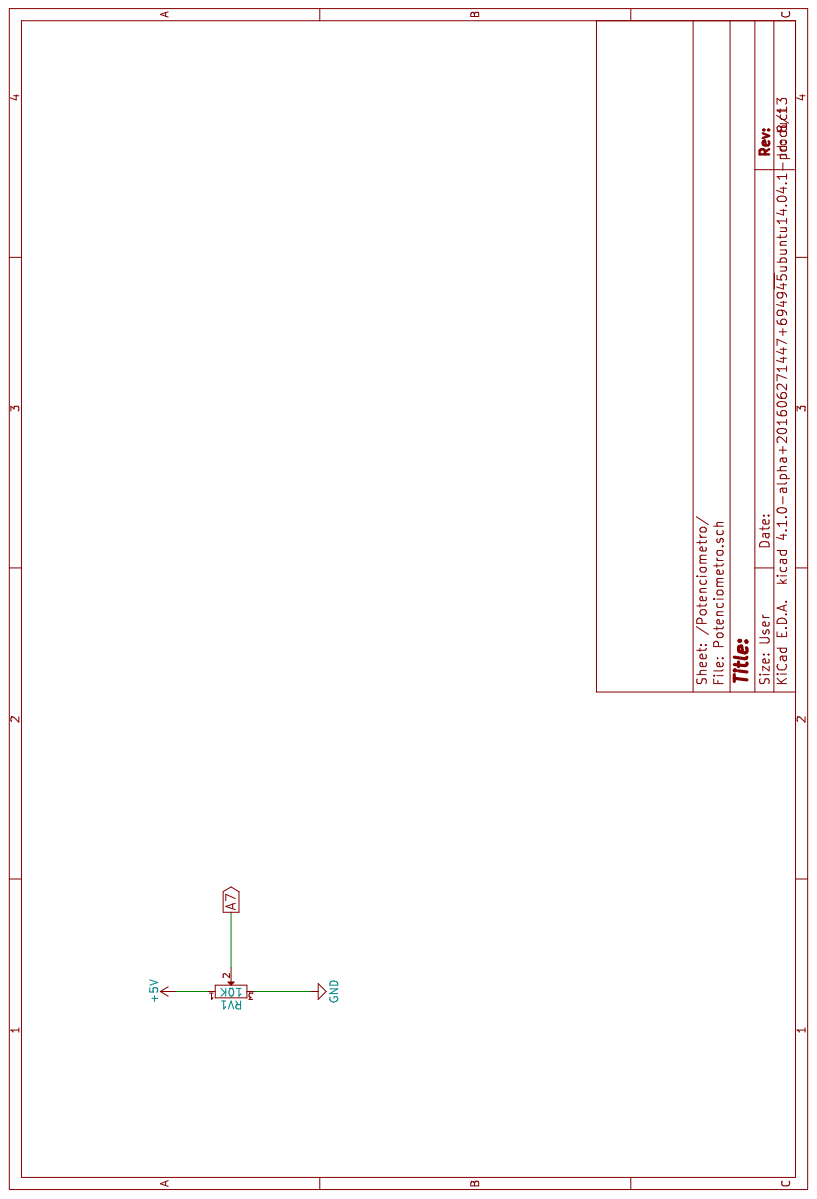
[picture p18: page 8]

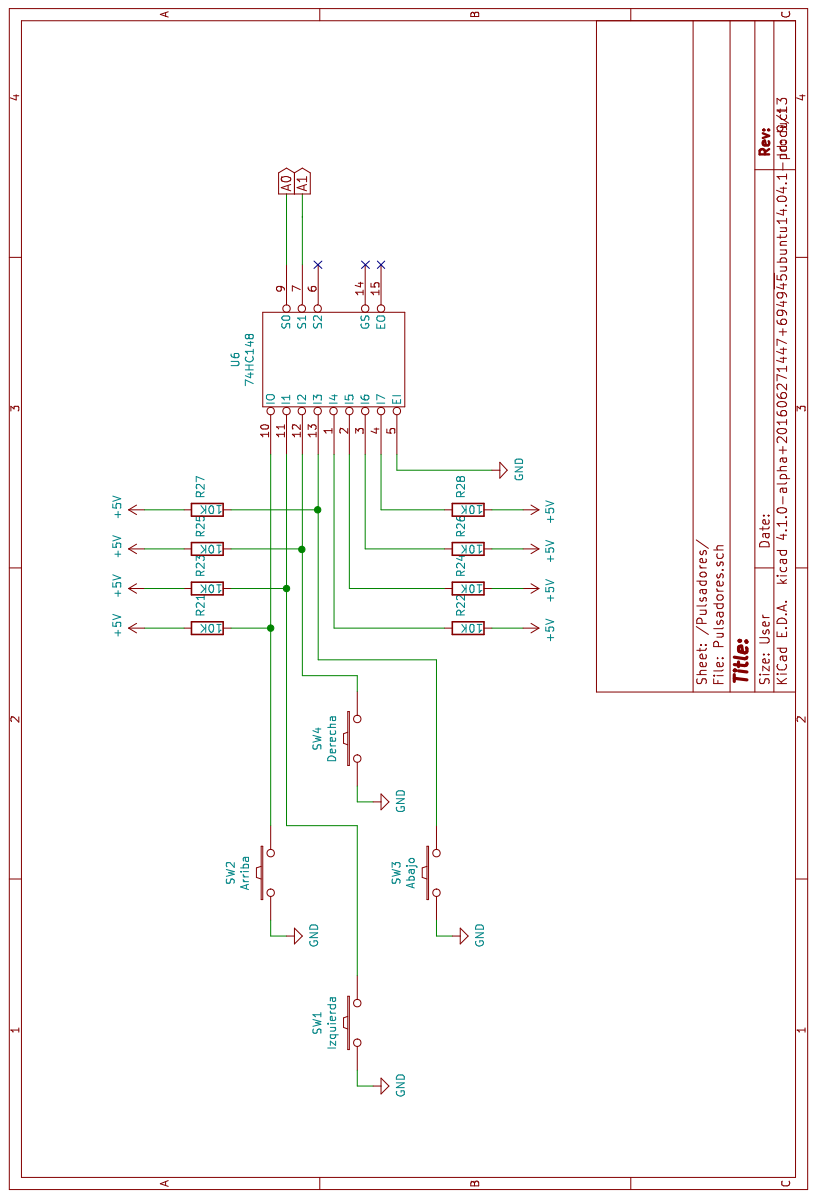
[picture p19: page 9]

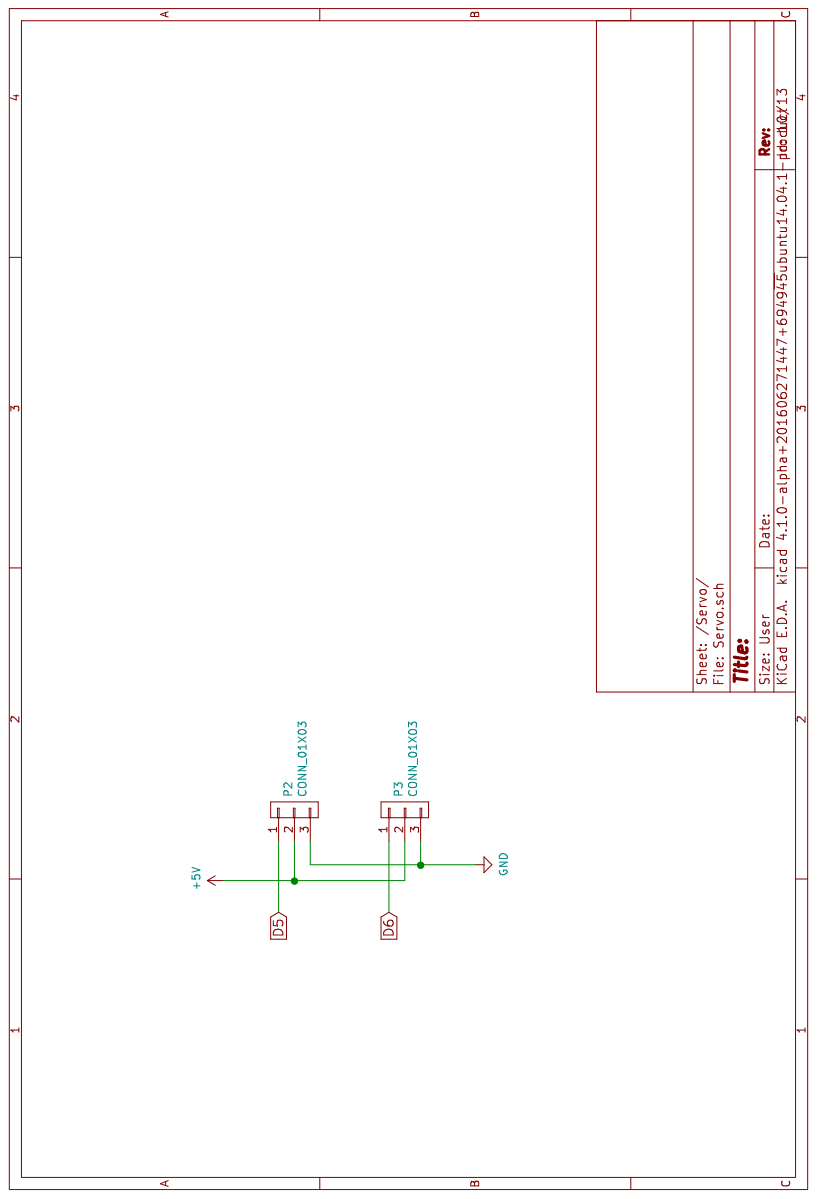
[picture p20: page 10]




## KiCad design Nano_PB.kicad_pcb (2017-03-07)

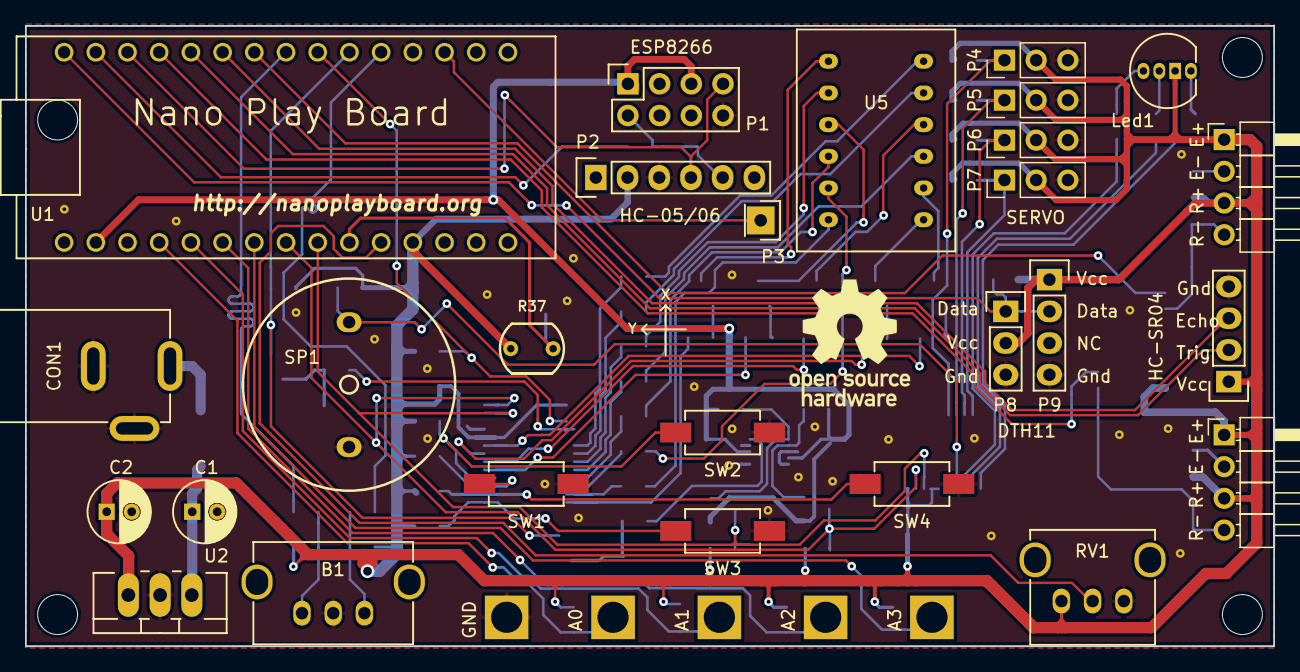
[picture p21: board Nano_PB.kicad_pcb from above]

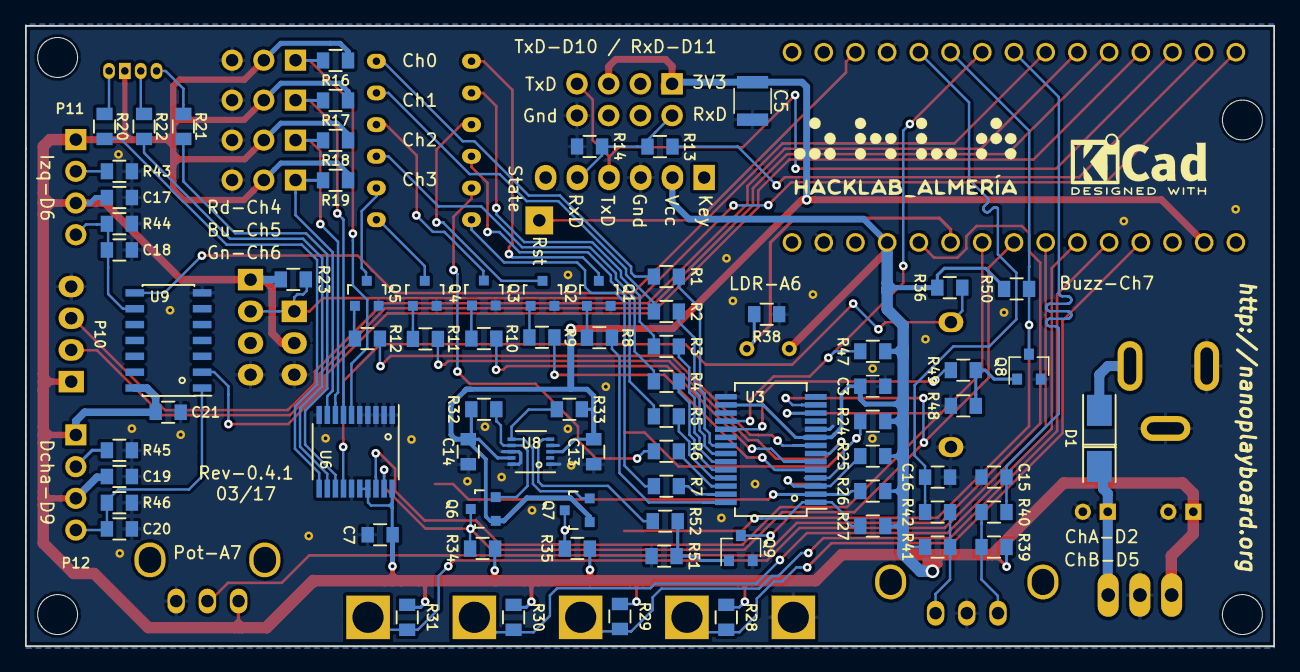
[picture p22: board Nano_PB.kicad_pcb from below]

Board: 2 copper layers, 100.0 x 49.7 mm, 135 parts (82 on the bottom side), 82 nets.

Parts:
B1: Encoder_Inc; ALPS_EC12E24_encoder_incremental
C1, C2: 0,33u; C_Radial_D5_L11_P2
C3, C7, C13, C14, C15, C16, C17, C19, C21: 100n; C_0805
C5: 47u; C_1210
C18, C20: 10n; C_0805
CON1: BARREL_JACK; Barrel_Jack_Hembra_CLIFF_FC68148
D1: 15MQ040N; DO-214AC
Gnd-Via: VAL**; Gnd-Via
Gnd-Via#2, Gnd-Via#3, Gnd-Via#4, Gnd-Via#5, Gnd-Via#6, Gnd-Via#7, Gnd-Via#8, Gnd-Via#9, Gnd-Via#10, Gnd-Via#11, Gnd-Via#12, Gnd-Via#13, Gnd-Via#14, Gnd-Via#15, Gnd-Via#16, Gnd-Via#17, Gnd-Via#18, Gnd-Via#19, Gnd-Via#20, Gnd-Via#21, Gnd-Via#22, Gnd-Via#23, Gnd-Via#24, Gnd-Via#25, Gnd-Via#26, Gnd-Via#27: VAL**; Gnd-Via
Led1: Led_RGB; LED_RGB_5mm_G_B_COM_R_Anodo_comun
P1: CONN_02X04; Socket_Strip_Straight_2x04
P2: CONN_01X06; Socket_Strip_Straight_1x06
P3: CONN_01X01; Socket_Strip_Straight_1x01
P4, P5, P6, P7: CONN_01X03; Pin_Header_Straight_1x03_Pitch2.54mm
P8: CONN_01X03; Socket_Strip_Straight_1x03
P9, P10: CONN_01X04; Socket_Strip_Straight_1x04
P11, P12: CONN_01X04; Pin_Header_Angled_1x04_Pitch2.54mm
P13, P14, P15, P16, P17: CONN_01X01; Pad_Conector_Cocodrilo
Q1, Q2, Q3, Q4, Q5, Q8, Q9: SMBT3904; SOT-23
Q6, Q7: BSS138; SOT-23
R1, R2, R3, R4, R5, R6, R7, R20, R21, R22: 120; R_0805
R8, R9, R10, R11, R12, R13, R38, R40, R42, R49, R52: 1K; R_0805
R14: 2K; R_0805
R16, R17, R18, R19, R24, R25, R26, R27, R36, R39, R41, R47, R50: 10K; R_0805
R23, R32, R33, R34, R35: 4K7; R_0805
R28, R29, R30, R31: 10M; R_0805
R37: LDR; LDR_TOKEN_PGM5_Series
R43, R45: 220R; R_0805
R44, R46, R48, R51: 47K; R_0805
RV1: 10K; ALP_RK09K111
SP1: BUZZER; LOUDITY_LD-BZPN-1705
SW1: Izquierda; CANAL_ELECTRONIC_DTSM-31N-B
SW2: Arriba; CANAL_ELECTRONIC_DTSM-31N-B
SW3: Abajo; CANAL_ELECTRONIC_DTSM-31N-B
SW4: Derecha; CANAL_ELECTRONIC_DTSM-31N-B
U1: Arduino_Nano
U2: LM7805CT; TO-220_Neutral123_Vertical_LargePads
U3: MCP23017; SSOP-28_5.3x10.2mm_Pitch0.65mm
U5: Matriz_5x7; Matriz_Led_7X5
U6: PCA9634; TSSOP-20_4.4x6.5mm_Pitch0.65mm
U8: MMA7660FC; DFN-10-1EP_3x3mm_Pitch0.5mm
U9: 40106; SOIC-14_3.9x8.7mm_Pitch1.27mm

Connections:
+3V3: C5.1, C13.1, C14.1, P1.1, P1.5, Q6.1, Q7.1, R32.1, R33.1, U1.17, U8.3, U8.9
+5V: C2.1, C3.1, C7.1, C17.1, C19.1, C21.1, Led1.3, P2.2, P4.2, P5.2, P6.2, P7.2, P8.2, P9.1, P10.1, P11.1, P11.3, P12.1, P12.3, R16.1, R17.1, R18.1, R19.1, R23.1, R24.1, R25.1, R26.1, R27.1, R28.1, R29.1, R30.1, R31.1, R34.1, R35.1, R36.1, R37.1, R39.1, R41.1, R47.1, R50.1, RV1.1, U1.27, U2.3, U3.9, U3.16, U6.16, U6.17, U6.20, U9.14
/Bluetooth/RxD: P1.2, P2.5, R13.1, R14.1
A0: P13.1, R28.2, U1.19
A1: P14.1, R29.2, U1.20
A2: P15.1, R30.2, U1.21
A3: P16.1, R31.2, U1.22
A4: Q6.3, R34.2, U1.23, U3.13, U6.19
A5: Q7.3, R35.2, U1.24, U3.12, U6.18
A6: R37.2, R38.2, U1.25
A7: RV1.2, U1.26
BUZZER: R36.2, SP1.1, U6.14
D2: C16.1, R42.2, U1.5
D3: Q8.3, Q9.3, R50.2, U1.6
D5: C15.1, R40.2, U1.8
D6: U1.9, U9.8
D7: P10.3, U1.10
D8: P10.2, U1.11
D9: U1.12, U9.2
D10: P1.7, P2.4, U1.13
D11: R13.2, U1.14
D12: P8.1, P9.2, R23.2, U1.15
GND: B1.C, C1.2, C2.2, C3.2, C5.2, C7.2, C13.2, C14.2, C15.2, C16.2, C17.2, C18.2, C19.2, C20.2, C21.2, CON1.2, CON1.3, Gnd-Via.1, Gnd-Via#2.1, Gnd-Via#3.1, Gnd-Via#4.1, Gnd-Via#5.1, Gnd-Via#6.1, Gnd-Via#7.1, Gnd-Via#8.1, Gnd-Via#9.1, Gnd-Via#10.1, Gnd-Via#11.1, Gnd-Via#12.1, Gnd-Via#13.1, Gnd-Via#14.1, Gnd-Via#15.1, Gnd-Via#16.1, Gnd-Via#17.1, Gnd-Via#18.1, Gnd-Via#19.1, Gnd-Via#20.1, Gnd-Via#21.1, Gnd-Via#22.1, Gnd-Via#23.1, Gnd-Via#24.1, Gnd-Via#25.1, Gnd-Via#26.1, Gnd-Via#27.1, P1.8, P2.3, P4.3, P5.3, P6.3, P7.3, P8.3, P9.4, P10.4, P17.1, Q1.2, Q2.2, Q3.2, Q4.2, Q5.2, Q8.2, Q9.2, R14.2, R38.1, R43.2, R44.2, R45.2, R46.2, R48.1, R51.1, RV1.3, SP1.2, SW1.1, SW2.1, SW3.1, SW4.1, U1.4, U1.29, U2.2, U3.10, U3.15, U3.17, U6.1, U6.2, U6.3, U6.4, U6.5, U6.10, U6.15, U8.1, U8.4, U8.8, U8.10, U9.7
LED_BLUE: R22.2, U6.12
LED_GREEN: R21.2, U6.13
LED_RED: R20.2, U6.11
unnamed: B1.A, R39.2, R40.1
unnamed: B1.B, R41.2, R42.1
unnamed: C1.1, D1.1, U2.1
unnamed: C18.1, P11.4, R44.1, U9.9
unnamed: C20.1, P12.4, R46.1, U9.1
unnamed: CON1.1, D1.2
unnamed: Led1.1, R21.1
unnamed: Led1.2, R22.1
unnamed: Led1.4, R20.1
unnamed: P11.2, R43.1
unnamed: P12.2, R45.1
unnamed: Q1.1, R8.1
unnamed: Q1.3, U5.1
unnamed: Q2.1, R9.1
unnamed: Q2.3, U5.3
unnamed: Q3.1, R10.1
unnamed: Q3.3, U5.10
unnamed: Q4.1, R11.1
unnamed: Q4.3, U5.7
unnamed: Q5.1, R12.1
unnamed: Q5.3, U5.8
unnamed: Q6.2, R32.2, U8.7
unnamed: Q7.2, R33.2, U8.6
unnamed: Q8.1, R48.2, R49.2
unnamed: Q9.1, R51.2, R52.2
unnamed: R1.1, U5.12
unnamed: R2.1, U5.11
unnamed: R3.1, U5.2
unnamed: R4.1, U5.9
unnamed: R5.1, U5.4
unnamed: R6.1, U5.5
unnamed: R7.1, U5.6
unnamed: R49.1, U3.19
unnamed: R52.1, U8.5
PA0: R1.2, U3.21
PA1: R2.2, U3.22
PA2: R3.2, U3.23
PA3: R4.2, U3.24
PA4: R5.2, U3.25
PA5: R6.2, U3.26
PA6: R7.2, U3.27
PA7: R8.2, U3.28
PB0: R27.2, SW3.2, U3.1
PB1: R26.2, SW4.2, U3.2
PB2: R25.2, SW1.2, U3.3
PB3: R24.2, SW2.2, U3.4
PB4: R9.2, U3.5
PB5: R10.2, U3.6
PB6: R11.2, U3.7
PB7: R12.2, U3.8
RESET: P3.1, U1.3
SERVO1: P4.1, R16.2, U6.6
SERVO2: P5.1, R17.2, U6.7
SERVO3: P6.1, R18.2, U6.8
SERVO4: P7.1, R19.2, U6.9
~RESET: R47.2, U1.7, U3.18

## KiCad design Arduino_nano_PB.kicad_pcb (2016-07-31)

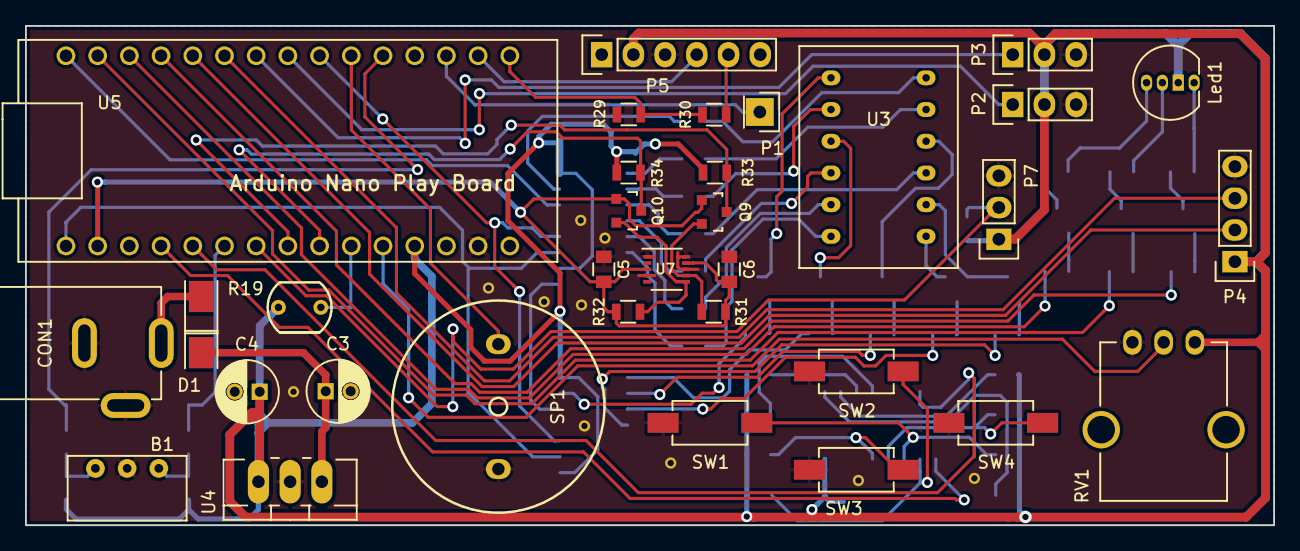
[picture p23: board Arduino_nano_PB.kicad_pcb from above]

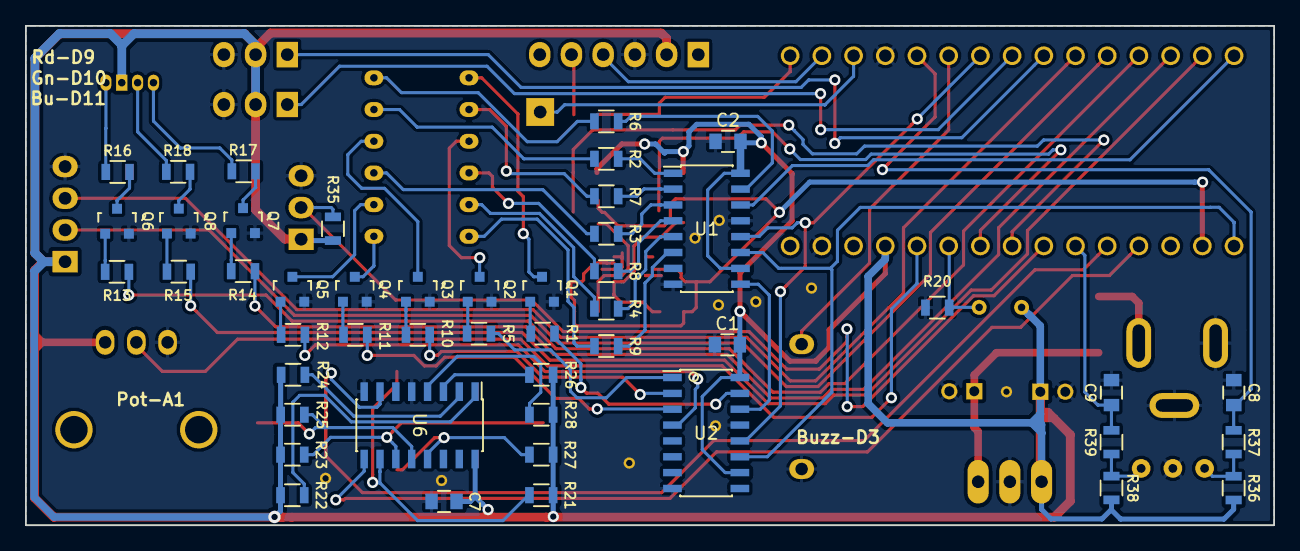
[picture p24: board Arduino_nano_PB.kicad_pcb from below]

Board: 2 copper layers, 100.0 x 40.0 mm, 91 parts (48 on the bottom side), 80 nets.

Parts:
B1: Encoder_Inc; Bourns_3315C_encoder_incremental
C1, C2, C5, C6, C7: 100n; C_0805
C3: 0,33u; C_Radial_D5_L11_P2
C4: 0,1u; C_Radial_D5_L11_P2
C8, C9: C; C_0805
CON1: BARREL_JACK; Barrel_Jack_Hembra_CLIFF_FC68148
D1: 1N4002; DO-214AC
Gnd-Via: VAL**; Gnd-Via
Gnd-Via#2, Gnd-Via#3, Gnd-Via#4, Gnd-Via#5, Gnd-Via#6, Gnd-Via#7, Gnd-Via#8, Gnd-Via#9, Gnd-Via#10: VAL**; Gnd-Via
Led1: Led_RGB; LED_RGB_5mm_G_B_COM_R_Anodo_comun
P1: CONN_01X01; Socket_Strip_Straight_1x01
P2, P3: CONN_01X03; Pin_Header_Straight_1x03
P4: CONN_01X04; Socket_Strip_Straight_1x04
P5: CONN_01X06; Socket_Strip_Straight_1x06
P7: CONN_01X03; Socket_Strip_Straight_1x03
Q1, Q2, Q3, Q4, Q5: SMBT3904; SOT-23
Q6, Q7, Q8: BC846B; SOT-23
Q9, Q10: BSS138; SOT-23
R1, R5, R10, R11, R12, R20, R30: 1K; R_0805
R2, R3, R4, R6, R7, R8, R9: 120; R_0805
R13, R14, R15, R31, R32, R33, R34: 4K7; R_0805
R16, R17, R18: 100; R_0805
R19: LDR; LDR_TOKEN_PGM5_Series
R21, R22, R23, R24, R25, R26, R27, R28: 10K; R_0805
R29: 2K; R_0805
R35, R36, R37, R38, R39: R; R_0805
RV1: 10K; POT_SR_PASIVES_R9011
SP1: BUZZER; LOUDITY_LD-BZPN-1705
SW1: Izquierda; CANAL_ELECTRONIC_DTSM-31N-B
SW2: Arriba; CANAL_ELECTRONIC_DTSM-31N-B
SW3: Abajo; CANAL_ELECTRONIC_DTSM-31N-B
SW4: Derecha; CANAL_ELECTRONIC_DTSM-31N-B
U1, U2: 74HC595; SOIC-16_3.9x9.9mm_Pitch1.27mm
U3: Matriz_5x7; Matriz_Led_7X5
U4: LM7805CT; TO-220_Neutral123_Vertical_LargePads
U5: Arduino_Nano
U6: 74HC148; SOIC-16_3.9x9.9mm_Pitch1.27mm
U7: MMA7660FC; DFN-10-1EP_3x3mm_Pitch0.5mm

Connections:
+3V3: C5.1, C6.1, Q9.1, Q10.1, R31.1, R32.1, U5.17, U7.3, U7.9
+5V: C1.1, C2.1, C4.1, C7.1, Led1.3, P2.2, P3.2, P4.1, P5.2, P7.1, R19.1, R21.1, R22.2, R23.1, R24.2, R25.1, R26.2, R27.1, R28.2, R33.1, R34.1, R35.1, R36.1, R38.1, RV1.1, U1.10, U1.16, U2.10, U2.16, U4.3, U5.27, U6.16
A0: U5.19, U6.9
A1: U5.20, U6.7
A2: C9.1, R39.2, U5.21
A3: P7.2, R35.2, U5.22
A4: Q9.3, R33.2, U5.23
A5: Q10.3, R34.2, U5.24
A6: R19.2, R20.2, U5.25
A7: RV1.2, U5.26
D0: P5.4, U5.2
D1: R29.1, R30.2, U5.1
D2: C8.1, R37.2, U5.5
D3: SP1.1, U5.6
D4: U1.12, U2.12, U5.7
D5: P2.1, U5.8
D6: P3.1, U5.9
D7: P4.3, U5.10
D8: P4.2, U5.11
D9: R13.2, U5.12
D10: R14.2, U5.13
D11: R15.2, U5.14
D12: U1.14, U5.15
D13: U1.11, U2.11, U5.16
GND: B1.C, C1.2, C2.2, C3.2, C4.2, C5.2, C6.2, C7.2, C8.2, C9.2, CON1.2, CON1.3, Gnd-Via.1, Gnd-Via#2.1, Gnd-Via#3.1, Gnd-Via#4.1, Gnd-Via#5.1, Gnd-Via#6.1, Gnd-Via#7.1, Gnd-Via#8.1, Gnd-Via#9.1, Gnd-Via#10.1, P2.3, P3.3, P4.4, P5.3, P7.3, Q1.2, Q2.2, Q3.2, Q4.2, Q5.2, Q6.2, Q7.2, Q8.2, R20.1, R29.2, RV1.3, SP1.2, SW1.1, SW2.1, SW3.1, SW4.1, U1.8, U1.13, U2.8, U2.13, U4.2, U5.4, U5.29, U6.5, U6.8, U7.1, U7.4, U7.8, U7.10
unnamed: B1.A, R36.2, R37.1
unnamed: B1.B, R38.2, R39.1
unnamed: C3.1, D1.1, U4.1
unnamed: CON1.1, D1.2
unnamed: Led1.1, R17.1
unnamed: Led1.2, R18.1
unnamed: Led1.4, R16.1
unnamed: P5.5, R30.1
unnamed: Q1.1, R1.1
unnamed: Q1.3, U3.1
unnamed: Q2.1, R5.1
unnamed: Q2.3, U3.3
unnamed: Q3.1, R10.1
unnamed: Q3.3, U3.10
unnamed: Q4.1, R11.1
unnamed: Q4.3, U3.7
unnamed: Q5.1, R12.1
unnamed: Q5.3, U3.8
unnamed: Q6.1, R13.1
unnamed: Q6.3, R16.2
unnamed: Q7.1, R14.1
unnamed: Q7.3, R17.2
unnamed: Q8.1, R15.1
unnamed: Q8.3, R18.2
unnamed: Q9.2, R31.2, U7.7
unnamed: Q10.2, R32.2, U7.6
unnamed: R1.2, U2.15
unnamed: R2.1, U3.11
unnamed: R2.2, U1.1
unnamed: R3.1, U3.9
unnamed: R3.2, U1.3
unnamed: R4.1, U3.5
unnamed: R4.2, U1.5
unnamed: R5.2, U2.1
unnamed: R6.1, U3.12
unnamed: R6.2, U1.15
unnamed: R7.1, U3.2
unnamed: R7.2, U1.2
unnamed: R8.1, U3.4
unnamed: R8.2, U1.4
unnamed: R9.1, U3.6
unnamed: R9.2, U1.6
unnamed: R10.2, U2.2
unnamed: R11.2, U2.3
unnamed: R12.2, U2.4
unnamed: R21.2, SW2.2, U6.10
unnamed: R22.1, U6.1
unnamed: R23.2, SW1.2, U6.11
unnamed: R24.1, U6.2
unnamed: R25.2, SW4.2, U6.12
unnamed: R26.1, U6.3
unnamed: R27.2, SW3.2, U6.13
unnamed: R28.1, U6.4
unnamed: U1.9, U2.14
RESET: P1.1, U5.3

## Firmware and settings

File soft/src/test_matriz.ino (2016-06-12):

/* Este es un ejemplo del uso de la matriz de led's en la Placa Arduino Nano Play Board
 *
 * Para el correcto funcionamiento de la matriz es necesario realizar un puente entre los 
 * pines D6 y A7, ya que el pin A7 que en la placa controla la carga de las salidas del 
 * registro de desplazamiento no es posible controlarlo como un pin de salida digital.
 * Esta carga pasa a controlarse con el pin D6 en la libreria "Registro.h"
 *
 * La libreria "MatrizLed.h" pretende proporcionar la estructura y metodos para el uso de la 
 * matriz a alto nivel. De momento no funciona correctamente y solo se incluye porque contiene 
 * la constante ascii[95][5] con la representacion de los caracteres del codigo ascii desde 
 * el 0x20 hasta el 0x7e
 *
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
 * This library is distributed in the hope that it will be useful, but WITHOUT ANY WARRANTY; 
 * without even the implied warranty of MERCHANTABILITY or FITNESS FOR A PARTICULAR PURPOSE. 
 * See the GNU General Public License for more details.                             
 *                                                                      
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
 * Creado en Jun/16 por AMR                                                                      
 */

#include <Arduino.h>
#include "Registro.h"
#include "MatrizLed.h"

MatrizLed matriz = MatrizLed();

char mensaje[] = "H o l a  @ H a c k L a b A l  a q u i  l a  A r d u i n o  N a n o  P l a y  B o a r d ";
//char mensaje[] = "Hola @HackLabAl aqui la Arduino Nano Play Board";
int columna[5]={2, 4, 5, 16, 17}; // Pines que controlan las distintas columnas de la matriz
Registro dato = Registro();  // Variable que controla el valor a representar en una columna

byte dat[5]; // Estructura a imprimir durante el desplazamiento de las letras
             // Permite representar cualquier patron en la pantalla de forma que se cargan parte de los 
             // caracteres conforme estos avanzan 


void setup(void) {

  Serial.begin(9600); // En caso de utilizar el ejemplo del puerto serie

}

void loop(void) {

//  Este ejemplo envia a la matriz los caracteres que recibe por el puerto serie
/*
  if (Serial.available()){
    imprimirCaracter(Serial.read(),50);
  }
  delay(10);
*/


//  Este ejemplo escribe texto del mensaje en la matriz
/*
  for (int k = 0; k < sizeof(mensaje); k++){
    imprimirCaracter(mensaje[k],50);
  }
*/

//  Este ejemplo desplaza el texto del mensaje por la matriz
  for (int k = 0; k < (sizeof(mensaje)*5-5); k++){
    // el restar 0x20 es para cuadrar el valor del ascii del caracter y
    // el indice en la libreria de caracteres, ya que esta tiene representados
    // desde el valor 0x20 hasta el 0x7e
    dat[0]=ascii[mensaje[k/5]-0x20][k%5];
    dat[1]=ascii[mensaje[(k+1)/5]-0x20][(k+1)%5];
    dat[2]=ascii[mensaje[(k+2)/5]-0x20][(k+2)%5];
    dat[3]=ascii[mensaje[(k+3)/5]-0x20][(k+3)%5];
    dat[4]=ascii[mensaje[(k+4)/5]-0x20][(k+4)%5];

    imprimirPatron(dat,7);
  }
  delay(1000);

}


// Muestra en la matriz el caracter enviado durante n veces consecutivas
// TODO : Eliminar el bucle del numero de veces a representar para evitar que
//        Programa se quede en el bucle y permita realizar otras cosas en cada ciclo de programa
void imprimirCaracter(char letra, int veces){

  for (int n=0; n < veces; n++){
    if ((letra >= 0x20) & (letra <=0x7e)) {   // Si el caracter esta dentro del rango de la biblioteca

      for(int i = 0; i < 5; i++){
        dato.Write(ascii[letra-0x20][i]);    // Carga el dato a imprimir en la columna
        digitalWrite(columna[i], HIGH);      // y activa la columna correspondiente
        delay(2);
        digitalWrite(columna[i], LOW);       // Despues la apaga
      }

    } else {                            // Si no imprime un espacio

      for(int i = 0; i < 5; i++){
        dato.Write(ascii[0][i]);             // Carga el dato a imprimir en la columna
        digitalWrite(columna[i], HIGH);      // y activa la columna correspondiente
        delay(2);
        digitalWrite(columna[i], LOW);       // Despues la apaga
      }
    }
  }
}

// Muestra en la matriz el patron enviado en el array patron
// TODO : Eliminar el bucle del numero de veces a representar para evitar que
//        Programa se quede en el bucle y permita realizar otras cosas en cada ciclo de programa
void imprimirPatron(byte patron[5], int veces)
{
  for (int n=0; n < veces; n++){
    for(int i = 0; i < 5; i++){
      dato.Write(patron[i]);    // Carga el dato a imprimir en la columna
      digitalWrite(columna[i], HIGH);      // y activa la columna correspondiente
      delay(2);
      digitalWrite(columna[i], LOW);       // Despues la apaga
    }
  }
}

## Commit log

2016-03-12 commit inicial
    [Arduino_nano_PB-B.Cu.gbl, Arduino_nano_PB-B.Mask.gbs, Arduino_nano_PB-B.Paste.gbp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]
2016-03-12 añadir imagenes y comenzar BOM
2016-03-12 corregido problema en los gerber de la cara bottom
    [Arduino_nano_PB-B.Cu.gbl, Arduino_nano_PB-B.Mask.gbs, Arduino_nano_PB-B.Paste.gbp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]
2016-03-13 actualizar lista de materiales
2016-03-13 error de formato en lista de materiales
2016-03-13 añadir valores en esquema y reordenar PCB
    [Arduino_nano_PB-B.Cu.gbl, Arduino_nano_PB-B.Mask.gbs, Arduino_nano_PB-B.Paste.gbp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]
2016-03-13 Añadir serigrafia capa bottom
    [Arduino_nano_PB-B.Cu.gbl, Arduino_nano_PB-B.Mask.gbs, Arduino_nano_PB-B.Paste.gbp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]
2016-03-13 Ajustar margen mascara soldadura a 7 mil
    [Arduino_nano_PB-B.Mask.gbs, Arduino_nano_PB-F.Mask.gts]
2016-03-14 incrementar corona de pads y vias a 0.2mm min
    [Arduino_nano_PB-B.Cu.gbl, Arduino_nano_PB-B.Mask.gbs, Arduino_nano_PB-B.Paste.gbp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]
2016-03-26 corregir errata en readme y capa de serigrafia superior
    [Arduino_nano_PB.kicad_pcb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]
2016-04-14 modificar tamaños de taladros en led RGB y resistencias
    [Arduino_nano_PB-B.Cu.gbl, Arduino_nano_PB-B.Mask.gbs, Arduino_nano_PB-B.Paste.gbp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]
2016-05-30 Añadido esquema electrico y distribucion de componentes
2016-06-05 Añadida libreria para representar caracteres. modificado ejemplo
2016-06-12 Modificada libreria registro para usar el pin D6 vs A7.
2016-06-24 añadidas referencia a la libreria desarollada por @josejuansanchez y puertos disponibles
2016-06-24 añadir salto de linea
2016-07-18 corrige issue #2
    [Arduino_nano_PB-B.Cu.gbl, Arduino_nano_PB-B.Mask.gbs, Arduino_nano_PB-B.Paste.gbp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]
2016-07-24 Añadidos nuevos elementos al esquema de la placa
    [Acelerometro.sch, Alimentacion.sch, Arduino_nano_PB.sch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]
2016-07-29 añaadido zocalo para sensor de temperatura y primera distribucion sobre la PCB
    [Acelerometro.sch, Alimentacion.sch, Arduino_nano_PB.kicad_pcb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]
2016-07-31 finalizado enrutado provisional
    [Acelerometro.sch, Alimentacion.sch, Arduino_nano_PB.kicad_pcb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]
2016-08-06 finalizado el trazado y renombrado de archivos
    [Arduino_nano_PB-B.Cu.gbl, Arduino_nano_PB-B.Mask.gbs, Arduino_nano_PB-B.Paste.gbp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]
2016-08-06 Actualizados nuevos sensores en readme
2016-08-06 añadiendo valores del distribuidor a los componentes
    [Acelerometro.sch, Alimentacion.sch, Bluetooth.sch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]
2016-08-06 ordenar referencias de componentes
    [Acelerometro.sch, Alimentacion.sch, Bluetooth.sch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]
2016-08-07 ajustes en serigrafia y posicion de algunos componentes
    [Nano_PB-B.Cu.gbl, Nano_PB-B.Mask.gbs, Nano_PB-B.Paste.gbp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]
2016-08-07 Pcb enviada a fabricar
    [Nano_PB-B.Cu.gbl, Nano_PB-B.Mask.gbs, Nano_PB-B.Paste.gbp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]
2016-08-07 fichero borrado
    [Nano_PB.drl]
2016-08-07 actualizar imagenes de la placa
2016-08-07 Actualizado el esquema electrico
    [Acelerometro.sch, Alimentacion.sch, Bluetooth.sch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]
2016-08-08 Añadir modelos 3D
    [Nano_PB.kicad_pcb]
2016-08-08 se resiste la tabla
2016-09-16 corrige issue #10
    [Nano_PB-B.Cu.gbl, Nano_PB-B.Mask.gbs, Nano_PB-B.Paste.gbp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]
2016-09-16 actualizar pdf de guia para la fabricacion
2016-10-11 cambiados encoder y potenciometro
    [Acelerometro.sch, Alimentacion.sch, Bluetooth.sch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]
2017-01-07 añadidos driver para led y conectores para fotodiodos infrarrojos
    [Acelerometro.sch, Alimentacion.sch, Bluetooth.sch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]
2017-01-11 Modificada posicion pulsadores y añadir vias entre planos de masa
    [Nano_PB.kicad_pcb]
2017-01-12 corregida serigrafia inferior
    [Nano_PB.kicad_pcb]
2017-01-13 modificada posicion del modulo esp
    [Bluetooth.sch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]
2017-01-13 modificaciones menores en el trazado para optimizarlo
    [Nano_PB-B.Cu.gbl, Nano_PB-B.Mask.gbs, Nano_PB-B.Paste.gbp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]
2017-01-14 completar serigrafias
    [Nano_PB-B.Cu.gbl, Nano_PB-B.Mask.gbs, Nano_PB-B.Paste.gbp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]
2017-01-14 modificada posicion transistores bus I2C
    [Nano_PB-B.Cu.gbl, Nano_PB-B.Mask.gbs, Nano_PB-B.Paste.gbp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]
2017-01-14 ultimas modificaciones a la PCB
    [Nano_PB-B.Cu.gbl, Nano_PB-B.Mask.gbs, Nano_PB-B.Paste.gbp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]
2017-01-14 actualizar lista de componentes y descripcion en README
2017-01-14 actualizada tabla de uso de pines Arduino
2017-01-15 modificar imagenes de la placa
2017-01-16 añadidos pdf para montaje
2017-01-19 Se añade un expansor GPIO al esquema y se elminan registros y codificador
    [Acelerometro.sch, Alimentacion.sch, Bluetooth.sch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]
2017-01-21 finalizada la ubicacion de componentes para la V0.4
    [Acelerometro.sch, Bluetooth.sch, Buzzer.sch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]
2017-01-23 ordenar trazado, añadir vias de union de planos gnd
    [Nano_PB.kicad_pcb]
2017-01-24 Modificaciones menores en serigrafia
    [Nano_PB-B.Cu.gbl, Nano_PB-B.Mask.gbs, Nano_PB-B.Paste.gbp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]
2017-01-25 Revisado V0.4. Actualizados gerber y esquemas
    [Acelerometro.sch, Alimentacion.sch, Bluetooth.sch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]
2017-01-25 version definitiva V0.4
    [Nano_PB-B.Cu.gbl, Nano_PB-B.Mask.gbs, Nano_PB-B.Paste.gbp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]
2017-01-25 actualizado README y BOM a la V0.4
2017-03-03 corregir errata en valores BOM
2017-03-03 corregidos valores en esquema y simbolos corruptos
    [Acelerometro.sch, Alimentacion.sch, Bluetooth.sch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]
2017-03-03 cambiadas huellas erroneas en U3 y U9. Corrige issues #17 y #18
    [Nano_PB.kicad_pcb]
2017-03-04 modificar posicion de vias de alimentacion proximas al chasis del encoder
    [Nano_PB.kicad_pcb]
2017-03-07 finalizada V0.4.1 corrige #17, #18 y #19
    [Acelerometro.sch, Alimentacion.sch, Bluetooth.sch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]

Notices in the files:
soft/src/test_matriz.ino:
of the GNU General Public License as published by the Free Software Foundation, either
